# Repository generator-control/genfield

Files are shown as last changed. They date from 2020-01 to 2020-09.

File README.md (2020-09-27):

#genfield
This repo started as a clone of the winch battery-to-invertor contactor control repo. See GliderWinchItems/contactor.

The hardware uses the f103Ard pcb (see GliderWinchCommons/embed/svn_sensor/hw/trunk/eagle/f103Ard) to control the generator field and throttle.

The processor is Blue Pill STM32F103 sub-board that mounts on the pcb.
The key configuration items of the board--
- Non-isolated CAN driver 
- Two Hall-effect current sensors for battery and motor currect
- Two isolated FET drivers for contactors using off-board sub-board
- Isolated high voltage measurement via isolated uart RX
- One small fet to pull invertor /enable line

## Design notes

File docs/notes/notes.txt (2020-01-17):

notes.txt
09/21/2019

1.  The "rig" was put together for test & debugging, so some repackaging
might be in order.

2. Blue Pill high voltage module glued to platform

Therefore, platform needs a spacer to sit flat.

3. Tamura 100a included

I had one with no immediate need. Calibration is based on this unit.

4. Screws

These are wood screws. They tend to crack the the top few layers of 
the post when they are screwed in. One hears a slight crack when 
they are first screwed in. At the time I had not found a source of 
self-tapping plastic screws.

5. Cabling ready to test

The interconnections are in place. These could be replaced by 
hard-wiring for a final package. Vias beside each RJ jack allow
easy soldering.

6. Aux contact feature not tested.

If something in the sw does not work with the Aux contact
feature the failure is to not connect. 

The hw has pull-up resistors so open circuit should appear as a
one bit in the sw. The hw should pull the line to gnd for closed
contact. The sw has a provision for reversing the sense for the
sw.

7. DMOC enable

The only test on this is that it pulls the line down for enable.
This is done after the program is in the CONNECTED state, which
has included a final contactor closure delay.

8. Flashing programs

I'm out of DiscoveryF4 boards, otherwise I would have included
one. The .doc file has a description of the connections for
using a DiscoveryF4 board.

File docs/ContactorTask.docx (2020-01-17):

A. Overview

The objective of the contactor “project” (project in the STM32CubeMX terminology) is to control the contactors that connect the battery string to the motor inverter (DMOC). A key part of this is pre-charging the DMOC capacitor so that when the contactor is closed the current surge is with the limits of the contactor contact rating.

Two modes are accommodated. A two contactor mode is based on two contactors. Contactor #1 connects the battery string to the DMOC plus. Contactor #2 connects the DMOC minus to the battery string minus. The pre-charge resistor is across contactor #2 contacts and when it is closed it shorts the pre-charge resistor.

The one contactor mode has one contactor (designated #1) and a small pre-charge relay (designated #2). The pre-charge relay connects the battery string to the DMOC plus via a pre-charge resistor. When the DMOC capacitor is charged sufficiently, the contactor is closed. The DMOC minus connects directly to the battery string minus.

Also involved is to detect special conditions and failures. E.g. if the battery string voltage is too low a command to connect will put the ContactorTask state in a fault condition and not respond to connect commands.

This project organization is based on using STM32CubeMX and FreeRTOS, and be event driven.

B. Hardware

The program is based on the f103Ard pcb in the following directory which is a motherboard for the Blue Pill module-- ~/GliderWinchCommons/embed/svn_sensor/hw/trunk/eagle/f103Ard

Three additional boards are connected to the f103Ard board: two fethe sub-boards which hold the isolated FET driver and FET for driving the contactor coil, and one custom module constructed on a perf-board with a Blue Pill module for isolated measurement of voltages of battery string and DMOC input.

1. f103ARd—Blue Pill Motherboard

The eagle files for this board can be found in--

~/GliderWinchCommons/embed/svn_sensor/hw/trunk/eagle/f103Ard

A key reference to the board usage is in the following--

~/GliderWinchItems/contactor/README.pins

Some modifications have been made to the board.

The connector arrangement, top view, with CAN RJ 45 jacks at the lower left hand--

a) Serial port: above the dc-dc switcher module, is a six pin header for FTDI type uart<->usb, used for debugging and console monitoring.

1) Gnd – rightmost pin

2) nc

3) nc

4) tx (on ftdi module)

5) rx (on ftdi module)

6) nc

b) Programming port: 4 pin header at bottom of Blue Pill module

1) gnd – rightmost pin|connects to Discovery hdr pin 3

2) – connects to Discovery hdr pin 2

3) – connects to Discovery pin 4

4) +3.3v (not used if motherboard powered from CAN) | connects to Discovery 3.3v on 50 pin hdr, if 3.3v power needed.

Note:

- The pin order of pins 2 & 3 reverses between the Blue Pill and Discovery.

- Discovery pins 1,5, 6 are not connected.

- The two SWD jumpers are removed on the STLINK hdr

c) DMOC enable—three pin, keyed, approximately center

FET pull-down for DMOC hardware enable.

1) gnd

2) FET drain

3) available for diode in case pwm an inductive load used. The diode is not installed.

d) RJ11 jacks for external units

Top left: isolated uart input from Blue Pill isolated high voltage sensor module

Top right: Hall-effect current sensor for battery string current

Bottom left: drive for isolated FET driver for contactor #1

Bottom right: drive for isolated FET driver for contactor #2 (or relay)

2. fethe—isolated FET driver sub-boards

The eagle files for this board can be found in--

~/GliderWinchCommons/embed/svn_sensor/hw/trunk/eagle/fethe

These boards hold the isolated FET driver, and power FET for driving the contactor coils.

R11 jack connects to the BP Motherboard

green led is on when Motherboard drive is high

green led is on FET drive plus is present

Connections

Three large holes, top, left--

gnd – contactor coil power ground (e.g. 12v minus)

+ - connect to 12v plus IF diode for pwm’ing coil is used

nearest FET – FET drain connect to contactor coil.

Note: instead of RJ11 cabling, direct wiring can be done using the viasadjacent to the RJ 11 jacks. Pass one wire through the via for strain relief and solder to the adjacent via, etc.

The right half of the fethe sub-boards are for various types of Hall-effect sensors and not use for this project.

3. Blue Pill isolated high voltage module

This board uses a Blue Pill module to measure four voltages with a common ground, with the ground isolated. A dc-dc module supplies 5v from the Motherboard. A photocoupler isolates the uart tx to the Motherboard.

The eagle files for this module can be found in--

~/GliderWinchItems/bpsensor/hw/eagle/bpsensor

The program layout is a clone of the contactor program with unused code removed.

The high voltage inputs go into a 2.2meg | 15K resistor divider.

Note: when programming the Blue Pill on this module the Discovery board and usb to the PC are NOT ISOLATED!

4. simulation module

The eagle files for this module can be found in--

~/GliderWinchItems/contactor/hw/eagle/simulator

This module is used for testing/debugging and simulates the two contactor modes. It does not simulate the auxiliary contact features and these have not bee tested in the program.

Connections to the module--

Note—the connectors are NOT keyed. Be careful!

top left: contactor #1

bottom left: contactor #2

gnd) connects to gnd (near FET on fethe subboard)

signal) connects to FET drain on fethe subboard

12v) connects to

a) fet driver supply pin

b) plus (diode) IF pwm of coil used

top middle: 12v supply

This supplies both the fet drive power and simulates a 12v battery string.

Bottom center—high voltage sensor connections

gnd – battery minus

1 – (hv1) battery string voltage

2 – (hv2) DMOC plus

3 – (hv3) DMOC minus

HV3 measures the voltage across the pre-charge resistor for the two contactor mode. (HV1-HV2) measures the voltage across the pre-charge resistor for one contactor (w pre-charge relay) mode.

Right most—discharge hdr

When the connect sequence ends the capacitor is charged and needs to be discharged for the next test cycle. A pushbutton plugged into the header allows for manually discharging the capacitor.

LEDs--

Dull green – 12v is present

Clear red (top) contactor #1 coil energized

Clear red (bottom) contactor #2 energized

Pre-charge capacitor simulation--

Resistor = 1K + 2.2K; Capacitor = 1000u

The 2.2K resistor was added to slow the charging to make it easier to observe what the program was doing.

Small resistors are in series with the 12v supply input and discharge hdr to limit smoke and dismay when bumbling about.

C. Program layout

STM32CubeMX generates ‘main’ plus the HAL and FreeRTOS routines. Added to the generated directories are the directories Ourwares and Ourtasks. Outwares holds our routines generally used across the winch applications. Ourtasks holds routines more specific to the project. The distinction is not rigid.

Makefile is generated by STM32CubeMX and is updated when ‘MX regenerates the project, if additional ‘MX files are added. To compile files from Ourwares and Ourtasks the lines are added to Makefile, but fortunately ‘MX does not overwrite the added lines. The list of files to be compiled in Makefile is obvious.

If floating point output in printf is used the Makefile LDFLAGS is modified to -u _printf_float instead of the -nano.

When main.c is generated by ‘MX the only task created is defaultTask. The initialization code is augmented with calls to files in Ourtasks and Ourwares for creation of tasks, buffers, etc. When there is a failure morse_trap is called and the green LED on the Blue Pill flashes a numeric code. A search of the files will turn up the location of the code.

Upon successfully completing the initialization phase of main, main calls the FreeRTOS scheduler and at that point it the various tasks are running. The defaultTask toggles the led every second as an indication that at least the defaultTask is running OK. If the it doesn’t toggle a likely problem is that there is a crash. Running openocd and telenet localhost 4444 and looking at the pc is the starting point. There are some asserts in FreeRTOS which can hang the program, e.g. trying to set a software timer with a timeout count of zero.

Besides initialization in main.c there is initialization in the tasks, e.g. obtaining a buffer for serial output. These can fail and have morse_traps for identification.

The main driver of the logic of the project is ContactorTask. The other tasks are more support for this task. The tasks running (the following in the order they are created in main initialization)--

1. defaultTask

One per second output of monitoring msgs, e.g. task stack usage, ADC readings, etc. Uses yprintf.

2. SerialTaskSend

Sending uart msgs from any task.

3. SerialTaskReceive

Receiving uart lines.

4. CanTxTask

Sending CAN msgs.

5. ContactorTask

Logic and operation of contactors.

6. MailboxTask

Sets up mailboxes for received CAN msgs and notifies task associated with the mailbox. can_iface interfaces our handling of CAN tx and rx msgs with the STM32CubeMX HAL CAN routines. The incoming CAN msg interrupt results in notification of a task, whose task-handle was initialized in the control block for that particular CAN module. (In the Blue Pill there is only one CAN module, but most F4 series can have two, and there are three in the F413 and F767.)

7. ADCTask

Sums ADC readings for DMA ½ and applies initial calibration.

8. Software timer 1

Periodic timer for keepalive/command msgs. Incoming command msgs reset the keepalive and result in a a status CAN msg response. When it times out the periodic callbacks send a status msg as a heartbeat in the absence of keepalive/command msgs.

9. Software timer 2

One-shot timer for waiting for expected contact closure, opening, etc.

10. Software timer 3

Timer to detect failure to receive the isolated high voltage readings.

Note: this task might be eliminated by using timer 1 to check if high voltage readings are not arriving.

D. ContactorTask specifics

This task is the central command for the contactor operation.

Following the initialization the endless loop--

1. Wait for notification

This is similar to ‘select’ in unix. It waits for one or more notifications to arrive. When a notification arrives a bit is set in a ‘noteval’ that identifies the source of the notification. The following notifications are in the program--

/* Task notification bit assignments. */

#define CNCTBIT00 (1 << 0) // ADCTask has new readings

#define CNCTBIT01 (1 << 1) // HV sensors usart RX line ready

#define CNCTBIT02 (1 << 2) // spare

#define CNCTBIT03 (1 << 3) // TIMER 3: uart RX keep-alive

#define CNCTBIT04 (1 << 4) // TIMER 1: Command Keep Alive

#define CNCTBIT05 (1 << 5) // TIMER 2: Multiple use delays

/* MailboxTask notification bits for CAN msg mailboxes */

#define CNCTBIT06 (1 << 6) // CANID_CMD: incoming command: cid_cmd_i

#define CNCTBIT07 (1 << 7) // CANID-keepalive connect command: cid_keepalive_i

#define CNCTBIT08 (1 << 8) // CANID-GPS time sync msg (poll msg): cid_gps_sync

2. Event handling

The notification is some sort of event. Each notification bit is checked and the associated notification is handled. E.g. a uart line received from the high voltage sensor requires extracting the three readings from the line and applying a calibration. The above notification list is also the event handling list.

Most notifications do not generate any actions. One exception is the keepalive/command timer timeout. When that occurs a CAN msg response with the status is always returned.

3. States

Following the handling of events, the current state is checked, i.e. any event results in a pass through the current state logic. A switch statement on the current state code calls a routine that handles that state. (Since these states are rather simple, the routines for all the states are combined into one .c file. For complicated situation each state might warrant a separate file.)

4. Output updates

Following the handling of the states any udpates to outputs are executed. The execution of states sets bits in an output status word and the outputs are updated (e.g. de-energizing contactor coils).

The conclusion of the updates ends the wait loop. The word with the notification bits handled during the loop feed back into the next wait-for-notification, to reset the bits in the FreeRTOS internal notification word. This sequence takes care of the case of notifications arriving during the execution of the loop.

E. States – brief

The list of states with very terse and incomplete description--

1. DISCONNECTED

This the initial state and final state with the contactors open. The DMOC enable FET is off. If the battery is voltage is too low the state will move to FAULTING, and onward to FAULTED.

2. CONNECTING

This and its substates take care of the sequence of energizing the contactors, checking the charging voltage, and either ending up going to FAULTING and onward to FAULTED.

3. CONNECTED

Contactors closed. DMOC enable FET is on. Only commands to disconnect or reset will exit this state to DISCONNECTING and onward to DISCONNECTED.

4. FAULTING,

Deals with de-energizing the contactors and the delay for opening.

5. FAULTED

Stuck in this state until a RESET command is received. A code specifying the reason for the fault shows up in the status msgs.

6. RESETTING

Almost the same as DISCONNECTING except for the resetting of the fault code.

7. DISCONNECTING

Similar to FAULTING except the end-point is DISCONNECTED rather than FAULTED.

8. OTOSETTLING

One time only state for readings to settle.

F. States – a little more description

We start with contactors open, etc. and the state being "disconnected."

Abbreviation:

KA - KeepAlive/command msg

Aux = Auxiliary contact

DISCONNECTED state

This state is changed when:

1) Battery string voltage is less than require to start a launch--

Set code number for battery string low.

New state: FAULTING

2) If Aux contacts are present on contactor #1, AND Aux 1 does not show OFF--

Set timer2 for longest of the two contactors opening delay

New state: FAULTING with code number for this fault.

3) If Aux contacts are present on contactor #2, AND Aux 2 does not show OFF. (Obviously, when there is one contactor and a pre-charge relay, there would be no Aux 2 contacts)--

Set timer 2 for contactor #2 opening delay

New state: FAULTING with code number for this fault.

4) CAN command (keep-alive) msg "connect" is received.

Set software timer2 for contactor #1 closure delay--

(approx 25 ms and if it has aux contacts this parameter might have to include

some delay if the aux contact close a bit behind the main contacts)

Set connecting substate to C1

New state: CONNECTING

CONNECTING state

substate C1 closing contactor #1

This state changes when:

1) Timer2 times out

Contactor #1 should now be closed, contactor #2 still open.

If aux1 present, and is not ON, then

Set code for aux1 not closing

New state: FAULTING

else

If two contactor config, and hv2 not approx equal hv1, then

Set code for contactor #1 didn’t close

New state: FAULTING

Set timer2 to minimum pre-charge duration (approx 3 secs)

New state: substate C2

substate C2 charging DMOC capacitor

This state changes when:

1) Timer2 times out.

Set timer for limit to extended pre-charge duration (4 secs?)

New state: substate C3

substate C3 charge DMOC cap until cutoff voltage

This changes state when:

1) If two contactors

hv3 is less than cutoff voltage (e.g. 10v)

else

(hv1-hv2) less than cutoff voltage

Set timer2 for contactor #2 closing delay

New state: substate C4

substate C4 contactor #2 closing

This changes state when:

1) If aux2 present and aux2 not closed

Set fault code: contactor #2 aux not closing

New state: FAULTING

2) Timer 2 times out.

If one contactor config,

de-energize contactor #2 (pre-charge relay)

New state: CONNECTED

CONNECTED state

This changes state when:

1) KA disconnect or reset commands received

Set timer2 to longest of contactors open delays.

New state: DISCONNECTING

DISCONNECTING state

Changes state when:

1) timer2 times out.

New state: DISCONNECTED

FAULTING state

Changes state when:

1) timer2 times out

New state: FAULTED

FAULTED state

The fault code list--

enum CONTACTOR_FAULTCODE

{

NOFAULT,

BATTERYLOW,

CONTACTOR1_OFF_AUX1_ON,

CONTACTOR2_OFF_AUX2_ON,

CONTACTOR1_ON_AUX1_OFF,

CONTACTOR2_ON_AUX2_OFF,

CONTACTOR1_DOES_NOT_APPEAR_CLOSED,

PRECHGVOLT_NOTREACHED,

CONTACTOR1_CLOSED_VOLTSTOOBIG,

CONTACTOR2_CLOSED_VOLTSTOOBIG,

KEEP_ALIVE_TIMER_TIMEOUT,

};

Changes state when:

1) KA command reset received

Clear fault code

New state: DISCONNECTED

G. Parameter list

Parameters are organized along the lines used for the bare metal and Derby database scheme. In the data base scheme parameters for a function are designated in PARAM_LIST_INSERT.sql and values for each instance of the function specified in PARAM_VAL_INSERT.sql. These files are found in

GliderWinchCommons/embed/svn_common/trunk/db

A java program outputs a file with these values as a struct in a .c file, which is compiled and loads into high flash for semi-permanent storage of the parameters for the particular instance of the function. When the program boots it copies the value in high flash into a sram working struct.

For contactor, the database/high-flash part is skipped and a routine with the parameter values hard-coded copies the parameters into the sram working struct. If the database/high-flash part is implemented (making possible online update of parameters) the only change for contactor would be to change the routine that hard-code initializes the working struct to one that copies the values from high-flash to the working struct.

For contactor there are two parameter lists. One is for the contactor function and the other is for the ADC. In the general sense the ADCs (as many as three modules) could serve multiple functions, however making a general multi-function interface is messy, e.g. one could use three of the ADCs, but only ADC1 accesses the internal voltage reference and temperature sensor, etc. Therefore, the parameters for the ADC were grouped separately from the contactor parameters.

The naming convention for the parameters is struct <NAME>LC (LC = Local Copy) giving rise to a .c and .h file. In this case--

adc_idx_v_struct.c [hard code set values]

adc_idx_v_struct.h [parameter struct definition]

contactor_idx_v_struct.c [hard code set values]

contactor_idx_v_struct.h [parameter struct definition]

A function instance requires more than just the parameters, so a struct is defined that contains the parameter struct plus the other other working variables. The naming convention for these structs is <NAME>FUNCTION.

adcparams.c

adcparams.h

ContactorTask.c

ContactorTask.h

In ContactorTask.h above the contactor function struc begins as--

struct CONTACTORFUNCTION

{

// Parameter loaded either by high-flash copy, or hard-coded subroutine

struct CONTACTORLC lc; // Parameters for contactors

struct ADCFUNCTION* padc; // Pointer to ADC working struct

The first entry, struct CONTACTORLC lc; // Parameters for contactors is the parameter struct for contactor. The second entry is pointer (mostly for convenience) to the adc function working struct. With this layout a single pointer to the contactor function struct accesses “everything” that is either a variable or parameter. The only parameters that might be in the executed code would be some universal scaling constants.

When the program starts the initialization calls the .c files above which in the case of the parameter list loads the parameters values into the working struct. A subsequent call to the .c files for the function struct initializes the working parameters, such as converting specified parameters such as milliseconds into timer ticks, and converting floating point (e.g. voltages) into scaled integers, range checks on parameters, pre-computing ratios for ADC calibrations, etc.

H. ADC

The ADC scans six channels, storing the 12b readings in a DMA circular buffer. The DMA interrupts at the ½ and end points of storing in the buffer, and the buffer length holds sixteen scans (six reading per scan) in each half. Upon a DMA interrupt the sixteen readings are summed for each channel. Since the maximum reading possible is 4095, the maximum sum is 65520 which fits in a uint16_t. The DMA interrupt notifies the ADCTask which carries out the summation and subsequent calibration of the readings.

The ADC calibration is based on using the internal voltage reference (Vref) rather than Vdd as the Vref is more stable. In the DiscoveryF4 Vdd can vary between about 2.85v and 3.3v depending whether the power source is the USB, as there is a diode drop involved. For the Blue Pill there is a 3.3v regulator and no diode involved, but the internal reference is more stable than the regulator.

The ADC routines in contactor deal with two types of measurements. One is absolute and the other ratiometric. The absolute measurement is based on the ratio of the ADC readings of the input to be measured and the Vref, and knowing the value of Vref. The result is independent of Vdd. The 5v and 12v supply voltages are examples. (For the high voltage sensor, the three high voltages would be absolute types of measurements.)

The ratiometric type of input is based on the ratio of the input to be measured and the ADC reading of the 5v supply. The Hall-effect current sensors use the 5v supply and output a signal from 0 – close to 5v. Their output is divided to limit the max voltage to the ADC to about 2.9v. The 5v supply is divided similarly. Knowing the ratio of the two dividers the result is independent of the 5v supply variations.

To simplify calibration, calibration parameters are specified in floating pt format, e.g. 5.03 volts. For computations the floating pt is scaled and computations done with integers.

A single pole iir filter, using int32_t, and expecting 16b numbers is used to smooth the summed ADC readings. The filter time constant and integer scaling are parameter inputs for each ADC channel.

(NOTE: filtering is provided by currently being skipped and the unfiltered readings used.)

For the contactor states that check for voltages above/below some threshold value, the threshold that is specified in floating pt is converted to a scaled uint32_t.

The internal temperature sensor is currently measured, but the formula to convert it to temperature is currently not coded. The code in F1 series is somewhat different than the F4 series that has calibration constants in the system memory. The temperature is chip temperature and as such not of much value for measuring ambient temperature, however it has use for compensating the internal reference voltage.

I. CAN msgs

ContactorTask.h has a summary of the CAN msg in the comments at the beginning of the file.

1. Function commands

The function command is a diagnostic/maintenance type of command. The early thinking was that one CAN id would be used to take of care of communication involving such things a online parameter update and retrieving variables that are not part of the operational aspect of the function. The hex CAN id is added to the database table CANID_INSERT.sql, and used in the initialization of the contactor parameter struct (see contactor_idx_v_struct.c).

For contactor retrieving raw ADC readings to be used in conjunction with an applied calibration voltage or current would be the main use of the function command.

cid_cmd_i (incoming) specifies a request in the first payload byte

cid_cmd_r (response) returns the requested readings

The first payload request byte code is specified in contactor_cmd_msg.c --

enum CONTACTOR_CMD_CODES

{

ADCRAW5V, // PA0 IN0 - 5V sensor supply

ADCRAWCUR1, // PA5 IN5 - Current sensor: total battery current

ADCRAWCUR2, // PA6 IN6 - Current sensor: motor

ADCRAW12V, // PA7 IN7 - +12 Raw power to board

ADCINTERNALTEMP, // IN17 - Internal temperature sensor

ADCINTERNALVREF, // IN18 - Internal voltage reference

UARTWHV1, // Battery voltage

UARTWHV2, // DMOC +

UARTWHV3, // DMOC -

CAL5V, // 5V supply

CAL12V, // CAN raw 12v supply

};

ADC requests send back a seven byte payload--

byte[0] : return of request code

byte[1]-[2]: 16b ADC sum reading

byte[2]-[6]: Float of calibrated reading

The high-voltage readings (essentially the same as ADC)--

byte[0] : return of request code

byte[1]-[2]: 16b sensor ADC reading sent via uart

byte[2]-[6]: Float of calibrated reading

CAL5V and CAL12V are the same as the ADC requests.

2. Polling

The contactor sends can send two CAN msgs in response to the CAN poll msg cid_gps_sync used for polling the POD. See contactor_idx_v_struct.c--

// CANID_HEX CANID_NAME CAN_MSG_FMT DESCRIPTION

p->cid_msg1 = 0x50400000; // CANID_MSG_CNTCTR1V : FF_FF : Contactor1: poll response: High voltage1:Current sensor1

p->cid_msg2 = 0x50600000; // CANID_MSG_CNTCTR1A : FF_FF : Contactor1: poll response: battery gnd to: DMOC+, DMOC-

One is for battery string voltage 1 and battery current 1 and the other for voltages between battery ground and DMOC+, DMOC-. These are sent in an eight byte payload as a pair of floats with units, volts & amps.

3. Heartbeat

Heartbeat messages have the same payload format as the Polled msgs, but lower priority CAN ids.

p->cid_hb1 = 0xFF800000; // CANID_HB_CNTCTR1V : FF_FF : Contactor1: Heartbeat: High voltage1:Current sensor1

p->cid_hb2 = 0xFF000000; // CANID_HB_CNTCTR1A : FF_FF : Contactor1: Heartbeat: High voltage2:Current sensor2

4. Keepalive/command

The keepalive msg carries the command to connect/disconnect/reset and also serves to let the contactor know that there is communication with the controller.

cid_keepalive_i (incoming) command

cid_keepalive_r (response) status

The response sends the current status. It is sent in response to each incoming keepalive msg and also whenever the state changes. If the keepalive msgs cease the keepalive timer timeout causes a status msg to be sent, making it like a heartbeat msg with the status.

J. cangateCON—cangate version for testing contactor

cangateCON is located in--

~/GliderWinchCommons/embed/svn_discoveryf4/PC/sensor/cangateCON/trunk

This version of cangate has some commands specific for testing the contactor. To compile cangateCON

cd to the above directory and type ./mm<enter>

To execute cangateCON (after setting up a gateway and hub-server)--

cd ~/GliderWinchCommons/embed/svn_discoveryf4/PC/sensor/cangateCON/trunk

./cangateCON 127.0.0.1 32123

More on setting up the whole test rig later.

command k

k - CONTACTOR: keep-alive

ka - Begin sending keep-alive msgs

kx - Stop keep-alive msgs

k0 - disconnect

k1 - connect

k2 - reset

This command handles the keepalive CAN msgs to/from the contactor.

Entering ‘k’ starts the command and keepalive msgs from contactor are decoded and displayed. The msgs from contactor may be either responses to keepalive msgs sent by cangateCON, or heartbeat msgs which are sent when the contactor keepalive timer has timed out, i.e. contactor was not receiveing keepalive msgs.

The keepalive msgs from contactor carry the status which is displayed, both with the numeric fields and ascii text for the codes that show the status of the contactor program progress.

After starting command ‘k’,

ka – starts sending keepalive msgs. The rate of status msgs from contactor will be faster than the heartbeat msgs.

kx – stops sending keepalive msgs.

k0 – disconnect command

returns contactor to disconnected state

k1 – connect command

starts the sequence for connecting

k2 – reset fault

When contactor goes into a fault state it remains until ‘k2’ sets the reset bit in the command msg.

command b

b - CONTACTOR: display polled msgs

Entering ‘b’ alone displays options

bp<enter>

CONTACTOR msg gps msg POLLED

default CAN IDs 50400000 50600000

bp aaaaaaaa bbbbbbbb<enter>

a = CAN ID msg1, b = CAN ID msg2

bh<enter>

CONTACTOR msg gps msg HEARTBEAT

default CAN IDs FF800000 FF000000

bh aaaaaaaa bbbbbbbb<enter>

a = CAN ID msg1, b = CAN ID msg2

The default CAN id for two CAN msgs from contactor are displayed. These can be overridden by entering ‘bp’ followed by the two CAN addresses. Note, one could display CAN payloads from any CAN msg(s) where the payload is two floats, i.e. the display is rather generic.

Entering ‘bp’ without additional data uses the default CAN addresses and displays polled msgs contactor sends in response to the gps/time sync msgs (64/sec). The polled response is two msgs that carry the three high voltage readings plus the current, all as floats in volts, or amps.

For example entering bp displayed, HV1, current, HV2, HV3 at 64 lines/sec--

Display two payload float pairs using CAN IDs: 50400000 50600000

12.468 0.000 0.027 0.027

12.458 0.000 0.027 0.027

…

Note that each line is payload from two CAN msgs and expects both msgs.

bh – same display as bp, but for heartbeats.

command s

s - CONTACTOR: command request to retrieve all readings

Send the maintenance commands and display the responses. CangateCON sends CAN msg to contactor. The first payload byte contains the code number for data. The response repeats the request code and adds the data.

ID: CAN node sends to us: E3600000 We send to CAN node: E360000C

TX: e360000c 1 0 : RX E3600000 7 00 FB F9 00 00 00 00 0: 63995 0.00 ADCRAW5V, PA0 IN0 - 5V sensor supply

TX: e360000c 1 1 : RX E3600000 7 01 BB B1 00 00 00 00 1: 45499 0.0 ADCRAWCUR1, PA2 IN2 - Current sensor: total battery current

TX: e360000c 1 2 : RX E3600000 7 02 C3 90 00 00 00 00 2: 37059 0.0 ADCRAWCUR2, PA4 IN4 - Current sensor: motor

TX: e360000c 1 3 : RX E3600000 7 03 75 3F 00 00 00 00 3: 16245 0.0 ADCRAW12V, PA7 IN7 - +12 Raw power to board

TX: e360000c 1 4 : RX E3600000 7 04 27 69 B6 23 0D 42 4: 26919 35.3 ADCINTERNALTEMP, IN17 - Internal temperature sensor

TX: e360000c 1 5 : RX E3600000 7 05 32 5D 00 00 00 00 5: 23858 0.000 ADCINTERNALVREF, IN18 - Internal voltage reference

TX: e360000c 1 6 : RX E3600000 7 06 38 05 DE 55 47 41 6: 1336 12.46 UARTWHV1, Battery voltage

TX: e360000c 1 7 : RX E3600000 7 07 03 00 ED 77 DE 3C 7: 3 0.03 UARTWHV2, DMOC +

TX: e360000c 1 8 : RX E3600000 7 08 03 00 69 C7 DE 3C 8: 3 0.03 UARTWHV3, DMOC -

TX: e360000c 1 9 : RX E3600000 7 09 00 00 00 00 00 00 9: 0 0.000 CAL5V, 5V supply

TX: e360000c 1 10 : RX E3600000 7 0A 00 00 00 00 00 0010: 0 0.000 CAL12V, CAN raw 12v supply

TX: e360000c 1 11 : RX E3600000 7 0B

Two instances of cangateCON, one with command k running, and one with command b running allow monitoring the pre-charging and status.

K. Running the test setup

The following three units are needed to run the test setup. Other units can also be on the CAN bus.

1. CAN bus

a) gps/logger generating time sync msgs

To observe the polled contactor msgs it needs time sync CAN msgs from the gps/logger.

b) gateway

c) contactor BP Motherboard

2. USB

A usb hub is needed for the following--

a) gateway FTDI module (for hub-server/socat to CAN bus)

b) contactor BP Motherboard: console monitoring

c) Discovery F4 STLINK (for reprogramming contactor)

3. contactor wiring

a) Wired to simulator, BP high voltage sensor modules and fethe subboards as described earlier.

b) Set jumpers for mode--

all to left = two contactor mode

all to right = contactor mode

c) Set use/ignore high voltage readings jump

not jumpered = use high voltage readings

jumper present = ignore high voltage reading logice

d) 12v to simulator module (which also powers the fethe boards).

e) Check that the following LEDs are “working”--

Both Blue Pill modules on the Montherboard and high voltage sensor should have a steady red led (showing it is powered) and one per second flashing green led (showing the program is running OK).

Each fethe subboard should have a steady bright green LED on (12v fet driver power).

Simulator module should have the dull green LED on (12v power).

4. Open window and Start hub-server and cangateCON

a) Determine port number of FTDI from gateway.

List serial ports devices--

ls /dev/ttyUSB*

Pull USB plug from the hub for gateway.

Up arrow and run above command again.

Note which device missing, e.g. dev/ttyUSB1

b) Start hub-server

hub-socat_b 32123 /dev/ttyUSB1 2000000

32123 = port number to be used

/dev/ttyUSB1 = gateway port as determined above

2000000 = baud rate for gateway<->socat

c) Check that hub-server is working

nc localhost 32123

CAN msgs should be seen ripping by.

d) Start an instance of cangateCON

Go to cangateCON directory--

cd ~/GliderWinchCommons/embed/svn_f~/GliderWinchCommons/embed/svn_discoveryf4/PC/sensor/cangateCON/trunk

./cangateCON 127.0.0.1 32123

The menu should come up--

### CANGATECON ### 08/03/2019

BAUDRATE is FIXED AT: 2000000 baud

argc 3

0 ./cangateCON

1 127.0.0.1

2 32123

Socket opened OK. IP: 127.0.0.1 PORT: 32123

CANID sql file opened!: ../../../../../svn_common/trunk/db/CANID_INSERT.sql

Control C to break & exit

a - ascii monitor of a CAN unit

d - list raw msgs

f - display fix: (e.g. f<enter>, or f E2600000<enter>

h - Photodetector level histogram from sensor

l - list unix time/date in heartbeat time msgs (l e1000000)

n - list msg id's and msg ct during 1 sec (coarse computer timing)

u - list msg id's and msg ct between CAN 1 sec time mgs (e.g. u 00600000)

m - list msgs for id entered 'm xxxxxxxx (CAN ID as 8 hex digits)'

q - Identify received msgs from CANID.sql file

r - send high priority RESET

s - CONTACTOR: command request to retrieve all readings

k - CONTACTOR: keep-alive

ka - Begin sending keep-alive msgs

kx - Stop keep-alive msgs

k0 - disconnect

k1 - connect

k2 - reset

b - CONTACTOR: display polled msgs

c - request & display launch parameters

w - list msgs float (wf) or integer (wi) payload with payload byte offset (wi1 E1800000)

x - cancel command

Control C to quit program

Enter command u--

CAN msg counts should appear if gps/logger is putting out time sync msgs. If not,

Try command n.

Enter command k for contactor. Something similar to the following should begin--

Using DEFAULT CAN IDs: Send E3800000 Rcv E3C00000

to use different CAN IDs, enter exactly in the following format

k aaaaaaaa bbbbbbbb<enter>

where: a = ID PC sends, b = ID PC receives

KA response (status): E3C00000 3 80 00 03 : 0 3 DISCONNECTED : NO_FAULT

KA response (status): E3C00000 3 80 00 03 : 0 3 DISCONNECTED : NO_FAULT

KA response (status): E3C00000 3 80 00 03 : 0 3 DISCONNECTED : NO_FAULT

…

e) Open a window and start minicom for console monitoring

Do a ‘ls /dev/ttyUSB*’, then pull the usb plug to the hub for the console FTDI module and repeat the command to see which port the console is on. Start minicom.

The console output depends on the sections of code enabled in the ‘main.c’ task--

void StartDefaultTask(void const * argument)

For example, the following updates at about once per second--

# 7 Unused Task stack space--

#Stack: defaultTask--- 109

#Stack: SerialTaskSend 92

#Stack: CanTxTask----- 84

#Stack: MailboxTask--- 64

#Stack: ADCTask------- 85

#Stack: ContactorTask- 76

#Stack: SerialReceiveTask 70

#GetFreeHeapSize: total: 7200 free 600 8.3% used: 6600

63995 45457 37097 16271 27127 23872 : 27129 372.9

UART ctr: 531

uart_hv 1337 1376 3

dscale0.0093252 0.0090523 0.0090649

hvcal 1222 1186 1188

hvc 1632592 1631936 3564

hv 1336 1376 3 <= from BP voltage sensor

dhvc 12.47 12.46 0.03 <= after calibration

ibattlow: 965 fbattlow: 9.00 hv[0]: 1336 battnow: 12.46

iprechgendv: 66 hv[IDXHV3].hvc: 3

HV by-pass pin: 1

THRES: 1752 78625 1631370 1633122 0

5. Open terminal window to observe contactor voltages/current

Start cangateCON. ‘cd’ to directory, as above, and start with same command line.

Enter command ‘bp’

The readings should be running past--

HV1 | current : HV2 | HV3

Press pushbutton to discharge capacitor. HV2 will likely drop somewhat. The latest offset was 0.027 volts.

6. Operate contactor

In the window with the ‘k’ command, running ‘ka’, it should be showing DISCONNECTED : NO_FAULT

If it is showing a fault, enter ‘k2’ to reset the fault state.

Enter ‘k1’ to start the connection.

Two contactor mode--

HV2 should jump to the batttery string voltage (i.e. the 12v supply).

HV3 should jump from near zero to nearly equal to the HV1, the battery string (12v supply) reading and begin dropping as the capacitor charges.

The status msgs should show “CONNECTING”.

The substate code will step to 1 for the minimum duration pre-charge, regardless of voltage, followed by step 2 which begins checking for the voltage threshold for closing contactor #2. If the threshold is not reached before the time expires it goes to a fault state and with the status message showing the fault.

Varying the timing and voltage parameters and recompiling/flashing can be done to demonstrate the various fault conditions.

L. Program compiling/flashing

1. Connect a DiscoveryF4 or Nucleo board to the Blue Pill programming port.

a) Remove the two jumpers on the STLINK header on the DiscoveryF4 board.

b) Connect the three wires from the SWD (six pin) header on the DiscoveryF4 board to the Blue Pill header as detailed earlier. Note that the wire sequence reverses for one pair.

c) USB cable from usb hub on PC to STLINK connector of DiscoveryF4

2. Open a window and cd to the project code--

cd ~/GliderWinchItems/contactor

Start compilation--

./mm

On my computer success produces--

deh@ASUS:~/GliderWinchItems/contactor$ ./mm

make: Nothing to be done for 'all'.

make: Nothing to be done for 'all'.

---- PATHS for OPENOCD ----

OPENOCD_SCRIPTS: /usr/share/openocd/scripts

OPENOCD_FLAHSER: /usr/share/openocd/scripts/interface/stlink-v2.cfg

OPENOCD_BOARD: /usr/share/openocd/scripts/board/olimex_stm32_h103.cfg

FLASH FILE NAME: /contactor.srec

_FLASHNAME: /usr/bin/make

DIR_SREC: /home/deh/GliderWinchItems/contactor/build

Open On-Chip Debugger 0.9.0 (2018-01-24-01:05)

Licensed under GNU GPL v2

For bug reports, read

http://openocd.org/doc/doxygen/bugs.html

Info : auto-selecting first available session transport "hla_swd". To override use 'transport select <transport>'.

Info : The selected transport took over low-level target control. The results might differ compared to plain JTAG/SWD

adapter speed: 1000 kHz

adapter_nsrst_delay: 100

none separate

Info : Unable to match requested speed 1000 kHz, using 950 kHz

Info : Unable to match requested speed 1000 kHz, using 950 kHz

Info : clock speed 950 kHz

Info : STLINK v2 JTAG v34 API v2 SWIM v0 VID 0x0483 PID 0x3748

Info : using stlink api v2

Info : Target voltage: 2.889882

Info : stm32f1x.cpu: hardware has 6 breakpoints, 4 watchpoints

target state: halted

target halted due to debug-request, current mode: Thread

xPSR: 0x01000000 pc: 0x08009f58 msp: 0x20005000

auto erase enabled

Info : device id = 0x20036410

Info : flash size = 64kbytes

Info : Padding image section 0 with 4 bytes

target state: halted

target halted due to breakpoint, current mode: Thread

xPSR: 0x61000000 pc: 0x2000003a msp: 0x20005000

wrote 62464 bytes from file /home/deh/GliderWinchItems/contactor/build/contactor.srec in 3.646678s (16.728 KiB/s)

shutdown command invoked

deh@ASUS:~/GliderWinchItems/contactor$

During the flashing phase the green LED on the Blue Pill module board will stop. If the program doesn’t crash when it starts up the green LED begins one second on/off flashing again.

Most errors are trapped with the ‘morse.c’ which flashes a two digit code number on the green LED. That code number can be found in the source code to locate where it went wrong. These are generally initialization faults.

If the green LED doesn’t flash there is likely FreeRTOS not happy. The most common problem is there is not enough sram for either system stack or the heap. The allocation can be adjusted

at line 106 in--

~/GliderWinchItems/contactor/Inc/FreeRTOSConfig.h

However, re-running STM32CubeMX will overwrite this if the code is regenerated. Therefore, if a new value is settled upon, go to STM32CubeMX and change it in the FreeRTOS section.

2. Modify parameters

Parameters can be modified to test the functioning of different fault conditions with the simulation module. Modifications will be necessary to adapt it to the real winch.

The parameters of interest are located in the directory--

~/GliderWinchItems/contactor/Ourtasks

The parameters are loaded into a sram struct during initialization. The values are currently loaded by executing the code in--

contactor_idx_v_struct.c

Later, this file could be replaced with loading from a flat file in high-flash that can be updated via CAN, and is independent of re-flashing the program code.

Other files associated with contactor_idx_v_struct.c are--

ContactorTask.h

contactor_func_init.c

hwconfig has bit positions for the configurations. All bits off is the default. These are defined in--

contactor_idx_v_struct.h

fbattlow Defines the voltage below which will cause a low battery fault when in the disconnected state.

The section on timings are in milliseconds, which is converted to parameters to timer ticks during the execution of contactor_func_init.c during initialization.

Of particular interest is--

ddiffb4 – defines the voltage across the contactor (difference before closing) that will end the pre-charging state. If the timer times out during this state, it means the voltage had been expected to be reached, but failed; therefore, it goes to a fault state.

fdiffafter – defines the voltage across final contactor after it has been energized and after a short delay for closure it should be closed, above which results in a fault, which means the contactor may not have closed. There is an issue here with pwm’ing the coil. If the contactor is pwm’ed and the pwm percentage is too low the contactor could drop out. The state logic doesn’t cover this situation.

prechgmin_t – Duration for the minimum pre-charge time. The first phase of pre-charge is always this duration.

prechgmax_t – Following the above minimum duration, this duration times the state that the voltage is checked for terminating the pre-charge. The pre-charge state will be terminated if the voltage threshold is reached, in which case it was successful, or if the timer times out, in which case it failed.

If the jumper for ignoring the high voltage readings is in place, the pre-chargemax time will take place and it will not go to a fault state when the timer times out. Net—the pre-charge duration would be the sum of prechgmin_t plus prechgmax_t.

close1_t, close2_t – These are set long to be able to observer the LED on the simulator module.

PWM parameters are in percentage (0-100). The coil is energized at full ON for close1_t or close2_t duration. At the end of that time duration the FET is pwm’ed at the parameter percentage. The simulator coils drop out at around 40%.

fpwmpct1, fpwmpct2 – percent pwm ON time.

Note: A minor simplification could be made by not specifying if the coils are to be pwm’ed, but instead always pwm the coil (after the initial 100% pull duration), and specify the pwm percentage as 100% (which results in continuous ON) if no pwm is desired.

dcurrentdisconnect – Battery current threshold for disconnecting

Opening the contactors for the DISCONNECTING state is prevented if the battery string current is greater than this parameter. The code assumes the parameter is positive. If the battery string current is negative the logic reverses the sign so that negative battery string currents greater than this parameter also prevents opening the contactors. If this feature is not desired, then set the parameter to an impossibly large value, but so large as to run into scaling problems (since the floating pt parameter is converted to a scale integer which is used for the arithmetic). A value 10% greater than the max of the current sensor would be a good value.

Calibrations

1. High voltage readings

The Blue Pill high voltage sensor sends ADC measurement, and these are then filtered, and adjusted for offset and scale to yield voltage. The defaultTask in contactor ‘main.c’ lists the raw adc readings which can be used to adjust the calibration for the three voltages. The present calibration was done with the 12v supply and can expected to be close for voltages in the 300-400v range.

2. Battery current

The calibration parameters are hard-coded in the file--

adc_idx_v_struct.c

The calibrations for the 12v simulation testing are--

// Battery current: ADC1IDX_CURRENTTOTAL 1 // PA5 IN5 - Current sensor: total battery current

p->cal_cur1.iir.k = 10; // Filter time constant

p->cal_cur1.iir.scale = 2; // Filter integer scaling

p->cal_cur1.zeroadcve = 27183; // connected, no current: HE adc reading

p->cal_cur1.zeroadc5 = 63969; // connected, no current: 5v adc reading

p->cal_cur1.caladcve = 30186; // connected, cal current: adc reading

p->cal_cur1.dcalcur = 9.373; // connected, cal current: current * turns

The two ‘iir’ parameters define the filtering of the ADC readings.

Since the Hall-effect sensor is driven by the 5v supply and is ratiometric, the calibration uses both the sensor readings and the 5v supply readings to compute a ratio.

zeroadcve – This (i.e. the ‘ve’) is the adc reading for the sensor with no current.

zeroadc5 – The 5v adc reading under the same conditions as zeroadcve.

caladcve – The adc reading for the sensor with the calibration current

dcalcur – Calibration current in ‘amp-turns’. For the Tamura sensor multiple turns can be wound to allow a smaller calibration current to simulate a one turn large current, the parameter is the calibration current multiplied by the number of turns. It assumes the 5v supply reading has not drifted from the zeroadc5.

The console monitor, defaultTask, displays the readings--

5v cur1 cur2 12v temp vref

A 63985.9 27199.7 32852.6 16236.4 26867.9 23855.2

Relevant are the 5v and cur1 readings. In the above, the 5v reading is close to 65520, which is the maximum ADC reading summed 16 times, and is a result of the resistor divider. In the above the 27199.7 cur1 reading is the zero-current level.

When the contactor is in the DISCONNECTED state the 5v/cur1 ratio is computed and compared to the previous ratio, which is initially the ratio computed from the calibration values. If this new ratio is greater than +/- ZTOLERANCE, which is defined in adcparams.h, (currently 0.05), then it goes to a fault condition with the fault code for HE_AUTO_ZERO_TOLERANCE_ERR, which is defined in adcparams.h.

The auto-zeroing continues as long as the contactor is in the DISCONNECTED state.

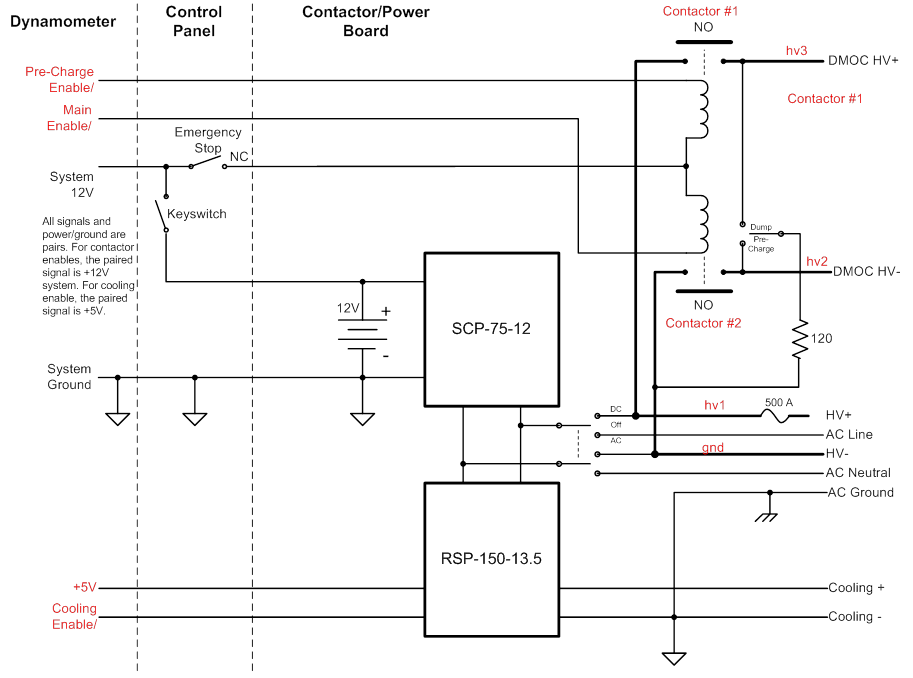
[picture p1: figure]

I have added labels (in red) for items I know. Take a look at this and see what else you would like added, removed, changed… I expect there to be several changes, some I have already thought on, but let me get your thoughts on this before I do more mods.

Contactor project rev 09/15/2019 07/15/2019 25

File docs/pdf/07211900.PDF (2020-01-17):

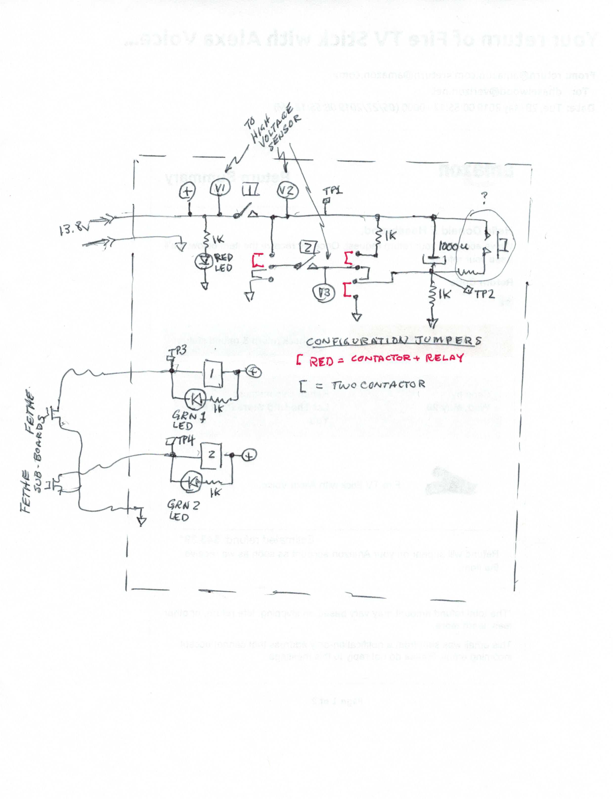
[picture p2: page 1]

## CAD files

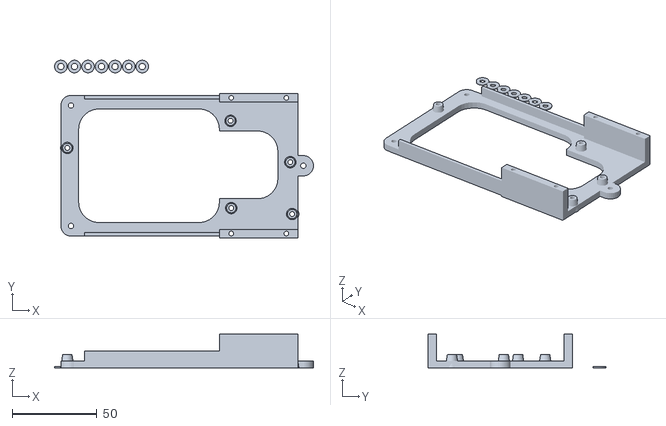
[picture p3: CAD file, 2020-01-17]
hw/openscad/platform2.stl
152.8 x 104.7 x 20.0

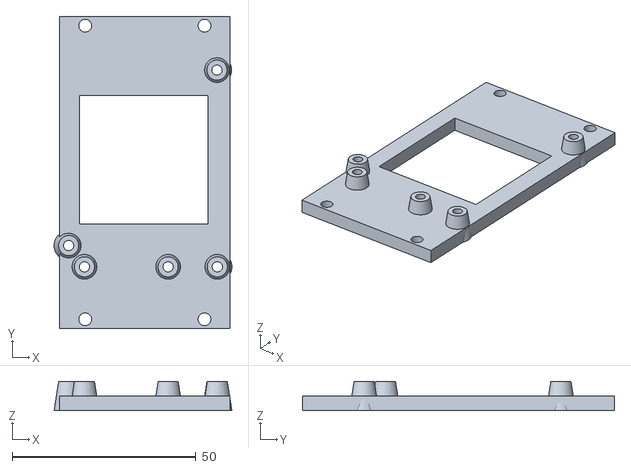
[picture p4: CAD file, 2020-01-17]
hw/openscad/pltop2.stl
48.5 x 85.0 x 8.00

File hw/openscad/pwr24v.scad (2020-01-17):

/* File: pwr24v.scad
 * Platform to hold 24v xfrmr and dc-dc 
 * Author: deh
 * Latest edit: 20200113
 */
 $fn = 30;
 
 thick = 4;

// Base
bx = 110; // Length
by = 85;  // Width
bt = 4;   // Thickness

// Transformer
tfhy = 58;   // Mtg hole spacing
tfhd = 3.5;  // Mtg hole diam

bhox = 3; // Base mtg hole offset from edge: x
bhoy = 3; // Base mtg hole offset from edge: y
module bhole(a)
{
	translate(a)
		cylinder(d =3.6,h=30,center=false);
}

acpx = 4;
acpy = 6;
acpz = 30;

module acpost(a)
{
	translate(a)
	{
		difference()
		{
			union()
			{
			}
			union()
			{
			}
		}
	}
}
dcpx = 4;
dcpy = 6;
dcpz = 45;

module dcpost(a)
{
	translate(a)
	{
		difference()
		{
			union()
			{
			}
			union()
			{
			}
		}
	}
}

module base()
{  
	difference()
	{
		union()
		{
			cube([bx,by,bt],center=false);
		}
		union()
		{
			// Base plate mounting holes
			bhole([   bhox,   bhoy,0]);
			bhole([bx-bhox,by-bhoy,o]);
			bhole([   bhox,by-bhoy,o]);
			bhole([bx-bhox,   bhoy,o]);

			// AC cord pcb posts


			// Rectified & dc-dc swrs post

	}
}

base();

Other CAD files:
hw/openscad/platform2.scad

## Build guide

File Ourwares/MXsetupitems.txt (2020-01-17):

MXsetupitems.txt

Items

1. Serial 

The last argument must match what was setup in 'MX--

/* Add bcb circular buffer to SerialTaskSend for usart1 */
	#define NUMCIRBCB1  16 // Size of circular buffer of BCB for usart6
	ret = xSerialTaskSendAdd(&huart1, NUMCIRBCB1, 1); // dma
	if (ret < 0) morse_trap(1); // Panic LED flashing

2. ADC

In adcparams.h the size must match 'MX--

#define ADC1IDX_ADCSCANSIZE   6 // Number ADC channels read

3.  morse.c

The LED set/reset must match the board, i.e. is the LED energized
by pull-down or pull-up.

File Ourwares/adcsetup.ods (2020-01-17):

 | mxusartusbcan |  | From datasheet formula
 | adc setup |  | Section | 5.3.21
 | 02/02/19 |  | 12-bit ADC | characteristics
 |  | Bus | 84
 |  | Divider | 8
 | K(sampling) | C(pf) | fadc*MHz) | 12bit | Rain |  | Sample tiime
 | 3 | 5 | 10.5 | 9.7040605278 | 5.79 |  | 0.3
 | 15 | 5 | 10.5 | 9.7040605278 | 29.34 |  | 1.4
 | 28 | 5 | 10.5 | 9.7040605278 | 54.86 |  | 2.7
 | 56 | 5 | 10.5 | 9.7040605278 | 109.82 |  | 5.3 |  |  | cts/volt
 | 84 | 5 | 10.5 | 9.7040605278 | 164.78 |  | 8.0 |  |  | 819 | 2.5 | 2047.5 | 2047.5
 | 112 | 5 | 10.5 | 9.7040605278 | 219.74 |  | 10.7 |  |  |  | 2047 | 1842.3
 | 144 | 5 | 10.5 | 9.7040605278 | 282.55 |  | 13.7
dynamometer | 480 | 5 | 10.5 | 9.7040605278 | 942.07 |  | 45.7
'MX
03/15/19 |  |  | ADC | Sample cycles | conv (us) |  |  | Offset | divider | Sensor amps | scale
 | PA1 | IN1 | 1 | 56 | 6.4761904762 |  | spare | ADC cts |  |  | amps
 | PA5 | IN5 | 2 | 56 | 6.4761904762 |  | Total battery current | 2047 | 0.6444444444 | 200 | 0.1086 |  | ACS770ECB-200B-PFF-T
 | PA6 | IN6 | 3 | 56 | 6.4761904762 |  | Current #1 motor | 2047 | 0.6444444444 | 600 | 0.3257 |  | L01Z600S05
 | PA7 | IN7 | 4 | 56 | 6.4761904762 |  | Current #2 motor | 2047 | 0.6444444444 | 400 | 0.2172 |  | L01Z400S05
 | PB0 | IN8 | 5 | 56 | 6.4761904762 |  | Speed control pot
 | PC1 | IN11 | 6 | 56 | 6.4761904762 |  | Control level (Hall sensor)
 | PC2 | IN12 | 7 | 56 | 6.4761904762 |  | +12 volt supply raw | 0 | 0.1525423729 | 19.0111111111
 | PC5 | IN15 | 8 | 56 | 6.4761904762 |  | +5 sensor supply voltage | 0 | 0.5465116279 | 5.3063829787
 |  | Temp | 9 | 480 | 46.8571428571 |  | Internal temperature sensor
 |  | Vref | 10 | 480 | 46.8571428571 |  | Internal voltage reference
 |  |  | DMA buffer | Num seq | 16
 |  |  |  | Total size | 320 |  |  | 10 | 10 | 0.5000 | 2.5000
 |  |  |  |  |  |  |  | 8.2 | 10 | 0.5495 | 2.7473
 |  |  |  | Time per seq | 145.5238095238 |  |  | 6.8 | 10 | 0.5952 | 2.9762
 |  |  | DMA buffer | Num seq | 16 | Per ½ dma
 |  |  |  | Per dma | 2328.380952381 | 1164.1904761905
 |  |  |  |  | 858.9659685864
 |  |  |  |  | DMA interrupt
 |  |  |  |  | Per sec | us per
 |  |  |  |  | 859 | 1164.1443538999

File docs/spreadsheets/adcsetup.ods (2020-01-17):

 | bpsensor |  | From datasheet formula
 | adc setup |  | Section | 5.3.21
 | 07/23/19 |  | 12-bit ADC | characteristics
 |  | Bus | 72
 |  | Divider | 6
 | K(sampling) | C(pf) | 12-bit ADC | 12bit | Rain |  | Sample tiime
 | 1.5 | 10 | 12 | 9.7040605278 | 1.29 |  | 0.1 |  |  | Divider |  |  |  |  |  |  |  |  |  | 14 | 14
 | 7.5 | 10 | 12 | 9.7040605278 | 6.40 |  | 0.6 |  | R1 (k) | R2 (k) | R|| (k) | Rseries(k) | Vdd (volts) | Ratio | Vin max | Vref | ADCvref | V1 | HV 100x | V1 | Vref scaled | ADCv1max
 | 13.5 | 10 | 12 | 9.7040605278 | 11.55 |  | 1.1 |  | 2200.00 | 18.70 | 18.54 | 2218.70 | 2.90 | 0.0084283589 | 344.1 | 1.200 | 27111.7 | 2.90 | 34407 | 47513 | 19660 | 65520 | 47511 | 0.7249603271
 | 28.5 | 10 | 12 | 9.7040605278 | 24.43 |  | 2.4 |  | 2200.00 | 18.00 | 17.85 | 2218.00 | 2.90 | 0.0081154193 | 357.3 | 1.200 | 27111.7 | 2.90 | 35734 | 47513 | 19660 | 65520 | 47511 | 0.7249603271
 | 41.5 | 10 | 12 | 9.7040605278 | 35.60 |  | 3.5 | ==> | 2200.00 | 15.00 | 14.90 | 2215.00 | 2.90 | 0.006772009 | 428.2 | 1.200 | 27111.7 | 2.90 | 42823 | 47513 | 19660 | 65520 | 47511 | 0.7249603271
 | 55.5 | 10 | 12 | 9.7040605278 | 47.62 |  | 4.6 |  | 2200.00 | 18.70 | 18.54 | 2218.70 | 3.30 | 0.0084283589 | 391.5 | 1.200 | 23825.5 | 3.30 | 39153 | 54067 | 19660 | 65520 | 54065 | 0.8249664307
 | 71.5 | 10 | 12 | 9.7040605278 | 61.36 |  | 6.0 |  | 2200.00 | 18.00 | 17.85 | 2218.00 | 3.30 | 0.0081154193 | 406.6 | 1.200 | 23825.5 | 3.30 | 40663 | 54067 | 19660 | 65520 | 54065 | 0.8249664307
dynamometer | 239.5 | 10 | 12 | 9.7040605278 | 205.63 |  | 20.0 | ==> | 2200.00 | 15.00 | 14.90 | 2215.00 | 3.30 | 0.006772009 | 487.3 | 1.200 | 23825.5 | 3.30 | 48730 | 54067 | 19660 | 65520 | 54065 | 0.8249664307
'MX
03/15/19 |  |  | ADC | Sample cycles | conv (us)
 | PA0 | IN0 | 1 | 41.0 | 4.4166666667 |  | Battery voltage
 | PA1 | IN1 | 1 | 41.0 | 4.4166666667 |  | DMOC+
 | PA2 | IN2 | 1 | 41.0 | 4.4166666667 |  | DMOC-
 | PA3 | IN3 | 1 | 41.0 | 4.4166666667 |  | spare
 | internal | IN17 | 1 | 252.0 | 22 |  | Internal temperature sensor
 | internal | IN18 | 1 | 252.0 | 22 |  | Internal voltage reference
 |  |  | DMA buffer | Num seq | 16
 |  |  |  | Total size ½ | 96
 |  |  |  | Time per seq | 61.6666666667
 |  |  | DMA buffer | Num seq PER ½ DMA | 16
 |  |  |  | Per dma | 986.6666666667
 |  |  |  |  | 1013.5135135135
 |  |  |  |  | DMA interrupt
 |  |  |  |  | Per sec | us per

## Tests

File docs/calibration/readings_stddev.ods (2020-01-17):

A | 64011.8 | 0.5 | 5.7 | 23974.7 | 26990.1 | 23854.4 | 1.4829618606 | 0.9440146568 | 9.6653361795 | 1.8218577889
A | 64008.7 | 0.5 | 5.6 | 23973.2 | 26987.1 | 23849.9 | 64010.4326039388 | 23973.6343544858 | 26969.1531728665 | 23852.5474835886
A | 64011.1 | 0.5 | 5.6 | 23974.1 | 26988.8 | 23853.5 | 0.0023167503 | 0.0039377203 | 0.035838486 | 0.0076380009
A | 64010.7 | 0.5 | 5.5 | 23974.1 | 26989.9 | 23852.2
A | 64012.1 | 0.5 | 5.5 | 23974 | 26989 | 23853.4
A | 64011.9 | 0.5 | 5.3 | 23973.6 | 26987.5 | 23852.9
A | 64010.7 | 0.5 | 5.5 | 23973.4 | 26987.8 | 23851.3
A | 64011.8 | 0.5 | 5.6 | 23974.4 | 26988.8 | 23854
A | 64012.5 | 0.5 | 5.7 | 23974.7 | 26989.5 | 23854.7
A | 64009.4 | 0.5 | 5.4 | 23973.7 | 26987.4 | 23849.7
A | 64012.2 | 0.5 | 5.4 | 23974.6 | 26990 | 23853.9
A | 64010.6 | 0.5 | 5.6 | 23974.3 | 26988.9 | 23851.4
A | 64013.1 | 0.6 | 5.9 | 23975.2 | 26988.8 | 23854.6
A | 64012.1 | 0.5 | 5.4 | 23974.4 | 26987.4 | 23853.1
A | 64011.3 | 0.5 | 5.5 | 23974.1 | 26987.3 | 23852.1
A | 64011.7 | 0.5 | 5.8 | 23974.4 | 26987.4 | 23853.4
A | 64010 | 0.5 | 5.6 | 23973.9 | 26985.8 | 23850.2
A | 64009.5 | 0.5 | 5.6 | 23974 | 26986.3 | 23849.5
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

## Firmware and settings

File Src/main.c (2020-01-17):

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

/* Includes ------------------------------------------------------------------*/
#include "main.h"
#include "cmsis_os.h"

/* USER CODE BEGIN Includes */

#include "stm32f1xx_hal.h"
#include <string.h>
#include "SerialTaskSend.h"
#include "SerialTaskReceive.h"
#include "CanTask.h"
#include "can_iface.h"
#include "canfilter_setup.h"
#include "getserialbuf.h"
#include "stackwatermark.h"
#include "yprintf.h"
#include "gateway_comm.h"
#include "gateway_CANtoPC.h"
#include "DTW_counter.h"
#include "yscanf.h"
#include "adctask.h"
#include "ADCTask.h"
#include "adcparams.h"
#include "adcparamsinit.h"
#include "gateway_PCtoCAN.h"
#include "morse.h"
#include "MailboxTask.h"
#include "GatewayTask.h"
#include "GenfieldTask.h"

/* USER CODE END Includes */

/* USER CODE BEGIN PTD */
struct CAN_CTLBLOCK* pctl0;	// Pointer to CAN1 control block

uint32_t debugTX1c;
uint32_t debugTX1c_prev;

uint32_t debug03;
uint32_t debug03_prev;

extern osThreadId SerialTaskHandle;
extern osThreadId SerialTaskReceiveHandle;
extern osThreadId CanTxTaskHandle;
extern osThreadId CanRxTaskHandle;
extern osThreadId GatewayTaskHandle;
extern osThreadId ADCTaskHandle;

uint8_t canflag;
uint8_t canflag1;

/* USER CODE END PTD */

ADC_HandleTypeDef hadc1;
DMA_HandleTypeDef hdma_adc1;

CAN_HandleTypeDef hcan;

TIM_HandleTypeDef htim1;
TIM_HandleTypeDef htim3;
TIM_HandleTypeDef htim4;

UART_HandleTypeDef huart1;
DMA_HandleTypeDef hdma_usart1_rx;
DMA_HandleTypeDef hdma_usart1_tx;

osThreadId defaultTaskHandle;
void SystemClock_Config(void);
static void MX_GPIO_Init(void);
static void MX_DMA_Init(void);
static void MX_CAN_Init(void);
static void MX_USART1_UART_Init(void);
static void MX_ADC1_Init(void);
static void MX_TIM4_Init(void);
static void MX_TIM1_Init(void);
static void MX_TIM3_Init(void);
void StartDefaultTask(void const * argument);

/**
  * @brief  The application entry point.
  * @retval int
  */
int main(void)
{
  /* USER CODE BEGIN 1 */
	BaseType_t ret;	   // Used for returns from function calls
	osMessageQId Qidret; // Function call return
	osThreadId Thrdret;
  /* USER CODE END 1 */
  

  /* MCU Configuration--------------------------------------------------------*/

  /* Reset of all peripherals, Initializes the Flash interface and the Systick. */
  HAL_Init();

  /* USER CODE BEGIN Init */
	DTW_counter_init();
  /* USER CODE END Init */

  /* Configure the system clock */
  SystemClock_Config();

  /* Initialize all configured peripherals */
  MX_GPIO_Init();
  MX_DMA_Init();
  MX_CAN_Init();
  MX_USART1_UART_Init();
  MX_ADC1_Init();
  MX_TIM4_Init();
  MX_TIM1_Init();
  MX_TIM3_Init();
  /* USER CODE BEGIN RTOS_MUTEX */
  /* add mutexes, ... */
  /* USER CODE END RTOS_MUTEX */

  /* USER CODE BEGIN RTOS_SEMAPHORES */
  /* add semaphores, ... */
  /* USER CODE END RTOS_SEMAPHORES */

  /* USER CODE BEGIN RTOS_TIMERS */
  /* start timers, add new ones, ... */
  /* USER CODE END RTOS_TIMERS */

  /* USER CODE BEGIN RTOS_QUEUES */
  /* add queues, ... */
  /* USER CODE END RTOS_QUEUES */

  /* Create the thread(s) */
  /* definition and creation of defaultTask */
  osThreadDef(defaultTask, StartDefaultTask, osPriorityIdle, 0, 304);
  defaultTaskHandle = osThreadCreate(osThread(defaultTask), NULL);

  /* USER CODE BEGIN RTOS_THREADS */
  /* add threads, ... */
/* =================================================== */

	/* Create serial task (priority) */
	// Task handle "osThreadId SerialTaskHandle" is global
	Thrdret = xSerialTaskSendCreate(0);	// Create task and set Task priority
	if (Thrdret == NULL) morse_trap(17);

	/* Add bcb circular buffer to SerialTaskSend for usart1 */
	#define NUMCIRBCB1  16 // Size of circular buffer of BCB for usart6
	ret = xSerialTaskSendAdd(&huart1, NUMCIRBCB1, 1); // dma
	if (ret < 0) morse_trap(1); // Panic LED flashing

	/* Add bcb circular buffer to SerialTaskSend for usart3 */
	#define NUMCIRBCB3  16 // Size of circular buffer of BCB for usart3
	ret = xSerialTaskSendAdd(&huart3, NUMCIRBCB3, 0); // char-by-char
	if (ret < 0) morse_trap(2); // Panic LED flashing

	/* Setup semaphore for yprint and sprintf et al. */
	yprintf_init();

	/* Create serial receiving task. */
	Thrdret = xSerialTaskReceiveCreate(1);
	if (Thrdret == NULL) morse_trap(21);

  /* definition and creation of CanTxTask - CAN driver TX interface. */
  Qidret = xCanTxTaskCreate(1, 32); // CanTask priority, Number of msgs in queue
	if (Qidret < 0) morse_trap(5); // Panic LED flashing

  /* definition and creation of CanRxTask - CAN driver RX interface. */
//  Qidret = xCanRxTaskCreate(1, 32); // CanTask priority, Number of msgs in extern osThreadId SerialTaskReceiveHandle;queue
//	if (Qidret < 0) morse_trap(6); // Panic LED flashing

	/* Setup TX linked list for CAN  */
   // CAN1 (CAN_HandleTypeDef *phcan, uint8_t canidx, uint16_t numtx, uint16_t numrx);
	pctl0 = can_iface_init(&hcan, 0, 32, 64);
	if (pctl0 == NULL) morse_trap(7); // Panic LED flashing
	if (pctl0->ret < 0) morse_trap(77);

	/* Setup CAN hardware filters to default to accept all ids. */
	HAL_StatusTypeDef Cret;
	Cret = canfilter_setup_first(1, &hcan, 15); // CAN1
	if (Cret == HAL_ERROR) morse_trap(9);

	/* Remove "accept all" CAN msgs and add specific id & mask, or id here. */
	// See canfilter_setup.h

	/* Genfield control. */
	Thrdret = xGenfieldTaskCreate(1);
	if (Thrdret == NULL) morse_trap(18);

	/* Create MailboxTask */
	Thrdret = xMailboxTaskCreate(3);
	if (Thrdret == NULL) morse_trap(19);

	/* Create Mailbox control block w 'take' pointer for each CAN module. */
	struct MAILBOXCANNUM* pmbxret;
	// (CAN1 control block pointer, size of circular buffer)
	pmbxret = MailboxTask_add_CANlist(pctl0, 16);
	if (pmbxret == NULL) morse_trap(16);

	/* Select interrupts for CAN1 */
	HAL_CAN_ActivateNotification(&hcan, \
		CAN_IT_TX_MAILBOX_EMPTY     |  \
		CAN_IT_RX_FIFO0_MSG_PENDING |  \
		CAN_IT_RX_FIFO1_MSG_PENDING    );

	/* Start CANs */
	HAL_CAN_Start(&hcan); // CAN1

	/* ADC summing, calibration, etc. */
	Thrdret = 	xADCTaskCreate(2);
	if (Thrdret == NULL) morse_trap(20);
	
/* =================================================== */

  /* USER CODE END RTOS_THREADS */

  /* Start scheduler */
  osKernelStart();
  
  /* We should never get here as control is now taken by the scheduler */

  /* Infinite loop */
  /* USER CODE BEGIN WHILE */
  while (1)
  {
    /* USER CODE END WHILE */

    /* USER CODE BEGIN 3 */
  }
  /* USER CODE END 3 */
}

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
/* USER CODE BEGIN Header_StartDefaultTask */
/**
  * @brief  Function implementing the defaultTask thread.
  * @param  argument: Not used 
  * @retval None
  */
/* USER CODE END Header_StartDefaultTask */
void StartDefaultTask(void const * argument)
{
  /* USER CODE BEGIN 5 */
	struct SERIALSENDTASKBCB* pbuf1 = getserialbuf(&huart1,96);
	if (pbuf1 == NULL) morse_trap(11);

	int ctr = 0; // Running count
	uint32_t heapsize;

// Copy of fast sum of ADC readings
int i;

// Number ADC readings per sec: 1153-1154.
extern uint32_t adcsumdb[6];// DMA sums
//extern uint32_t adcdbctr; // ADC DMA sum counter
double dt1;

extern struct GENFIELDFUNCTION genfieldfunction;
struct GENFIELDFUNCTION* pcf = &genfieldfunction;

osDelay(50); // Allow ADC task to get these initialized

// Temperature precomputed ratio check
if (pcf->padc->intern.dx25 < 0.1) morse_trap(48);

//double dxdvref = pcf->padc->intern.dvref * (1.0/4.3E-3);
if (pcf->padc->intern.dxdvref < 0.1) morse_trap(49);

// DTW time duration checks
extern uint32_t adcdbg2;

extern uint32_t dbgCE1;
uint32_t dbgCE1_prev = dbgCE1;

extern uint32_t dbgev04;


#define LOOPDELAY 1000
uint32_t tickct = xTaskGetTickCount();
int32_t loopdelay;

  /* Infinite loop */
  for(;;)
  {
//	tickct += LOOPDELAY;
//	loopdelay = (tickct - xTaskGetTickCount());
//	if (loopdelay < 1) morse_trap(333);
//   osDelay(loopdelay);
osDelay(1000);
//while( (dbggpsflag-dbggpsflag_prev) == 0);
//dbggpsflag_prev = dbggpsflag;

	HAL_GPIO_TogglePin(GPIOC,GPIO_PIN_13); // LED Green

#define SHOWSTACKWATERMARK
#ifdef SHOWSTACKWATERMARK
			// Following takes 1370791 sysclock ticks 19.0 ms (includes serial port wait)
			/* Display the amount of unused stack space for tasks. */
			yprintf(&pbuf1,"\n\n\r#%4i Unused Task stack space--", ctr++);
			stackwatermark_show(defaultTaskHandle,&pbuf1,"defaultTask---");
			stackwatermark_show(SerialTaskHandle ,&pbuf1,"SerialTaskSend");
			stackwatermark_show(CanTxTaskHandle  ,&pbuf1,"CanTxTask-----");
	//		stackwatermark_show(CanRxTaskHandle  ,&pbuf1,"CanRxTask-----");
			stackwatermark_show(MailboxTaskHandle,&pbuf1,"MailboxTask---");
			stackwatermark_show(ADCTaskHandle    ,&pbuf1,"ADCTask-------");
 		 stackwatermark_show(GenfieldTaskHandle,&pbuf1,"GenfieldTask-");
	stackwatermark_show(SerialTaskReceiveHandle,&pbuf1,"SerialReceiveTask");

			/* Heap usage (and test fp woking. */
  #define HEAPSIZELIST 
  #ifdef  HEAPSIZELIST
			heapsize = xPortGetFreeHeapSize();
			yprintf(&pbuf1,"\n\r#GetFreeHeapSize: total: %i free %i %3.1f%% used: %i\n\n\r",configTOTAL_HEAP_SIZE, heapsize,\
				100.0*(float)heapsize/configTOTAL_HEAP_SIZE,(configTOTAL_HEAP_SIZE-heapsize));
  #endif

#endif

#define SHOWSUMMEDADCCHANNELS
#ifdef  SHOWSUMMEDADCCHANNELS
		for (i = 0; i < 6; i++)
		{	
			yprintf(&pbuf1,"%7i ",adcsumdb[i]); // This is what routines work with
		}
		yprintf(&pbuf1, " :%7i %8.1f\n\r ", pcf->padc->intern.adcfiltemp, (double)(pcf->padc->intern.adcfilvref)/pcf->padc->intern.iiradcvref.pprm->scale);
#endif

#define SHOWEXTENDEDSUMMEDADCCHANNELS
#ifdef  SHOWEXTENDEDSUMMEDADCCHANNELS
		yprintf(&pbuf1, "\n\r     5v    cur1    cur2     12v    temp    vref\n\rA ");
		// Following loop takes about 450000 sysclock ticks 6.2 ms (includes waits for serial port)
		for (i = 0; i < 6; i++)
		{	
			yprintf(&pbuf1,"%8.1f",(double)(pcf->padc->chan[i].xsum[1])*(1.0/ADCEXTENDSUMCT));
		}
		yprintf(&pbuf1,"\n\r");
#endif

#define SHOWINTERNALTEMPERATURECALCULATIONS 
#ifdef SHOWINTERNALTEMPERATURECALCULATIONS
	/* Internal temperature computation check. */
	// The following takes 1418 sysclock ticks
	dt1 = (pcf->padc->intern.dx25 - (pcf->padc->intern.dxdvref * ((double)pcf->padc->intern.adcfiltemp / (double)pcf->padc->intern.adcfilvref )))  + pcf->padc->lc.calintern.drmtemp;

	yprintf(&pbuf1,"\n\rT degC: (doubles)%6.2f %6.2f (scaled int)%i\n\r", dt1,(double)pcf->padc->intern.itemp/(1<<ADCSCALEbits), adcdbg2,pcf->padc->intern.adccmpvref);
#endif

//      pcf->padc->chan[ADC1IDX_5VOLTSUPPLY].ival,  pcf->padc->v5.adcfil, 
//      pcf->padc->chan[ADC1IDX_12VRAWSUPPLY].ival, pcf->padc->v12.adcfil,
//#define SHOWADCDETAILS
#ifdef  SHOWADCDETAILS
	yprintf(&pbuf1,"\n\r%i %i %i %i %i %0.6f %0.4f : %0.4f\n\r",
      pcf->padc->v12.ival,
      pcf->padc->intern.adcfilvref,
      pcf->padc->intern.vref,
	   pcf->padc->v12.adcfil,
	   pcf->padc->lc.calintern.adcvdd,
      pcf->padc->v12.k,  
      (pcf->padc->v12.k * (double)pcf->padc->v12.ival * (1.0/(1<<ADCSCALEbits))), 
      pcf->padc->intern.dvref );

	yprintf(&pbuf1,"\n\rV v5: %0.3f  v12: %0.2f\n\r",
	  (pcf->padc->v5.k  * (double)pcf->padc->v5.ival  * (1.0/(1<<ADCSCALEbits))),
	  (pcf->padc->v12.k * (double)pcf->padc->v12.ival * (1.0/(1<<ADCSCALEbits))) );
#endif

#define SHOWHVUARTDATA
#ifdef  SHOWHVUARTDATA

yprintf(&pbuf1,"UART ctr: %i\n\ruart_hv%8i %9i %9i\n\r",dbgCE1-dbgCE1_prev,
  pcf->hv[0].hv,pcf->hv[1].hv,pcf->hv[2].hv);
dbgCE1_prev = dbgCE1;

/*
	double dscale;         // volts/tick
	double dhvc;           // HV calibrated
	uint32_t hvcal;        // Calibrated, scaled volts/adc tick
	uint32_t hvc;          // HV as scaled volts
	uint16_t hv;           // Raw ADC reading received from uart
*/
for (i = 0; i < 3; i++)
{
	pcf->hv[i].dhvc = (double)pcf->hv[i].dscale * (double)pcf->hv[i].hv;
}
yprintf(&pbuf1,"dscale%9.7f %9.7f %9.7f\n\r",pcf->hv[0].dscale,pcf->hv[1].dscale,pcf->hv[2].dscale);

yprintf(&pbuf1,"hvcal %9i %9i %9i\n\r",pcf->hv[0].hvcal,pcf->hv[1].hvcal,pcf->hv[2].hvcal);

yprintf(&pbuf1,"hvc   %9i %9i %9i\n\r",pcf->hv[0].hvc,pcf->hv[1].hvc,pcf->hv[2].hvc);

yprintf(&pbuf1,"hv    %9i %9i %9i\n\r",pcf->hv[0].hv,pcf->hv[1].hv,pcf->hv[2].hv);

yprintf(&pbuf1,"dhvc  %9.2f %9.2f %9.2f\n\r",pcf->hv[0].dhvc,pcf->hv[1].dhvc,pcf->hv[2].dhvc);

#endif

#define SHOWBATTERYLOWSTUFF
#ifdef  SHOWBATTERYLOWSTUFF

yprintf(&pbuf1,"ibattlow: %i  fbattlow: %0.2f  hv[0]: %i battnow: %0.2f\n\r",
   pcf->ibattlow, pcf->lc.fbattlow,
   pcf->hv[0].hv,
   (double)pcf->hv[0].dscale*(double)pcf->hv[0].hv);

yprintf(&pbuf1,"iprechgendv: %i hv[IDXHV3].hvc: %i\n\r",pcf->iprechgendv,pcf->hv[IDXHV3].hv);

#endif

#ifdef SHOWCANMSGCOUNTSATVARIOUSPOINTS
extern uint32_t dbgcantxctr;
extern uint32_t dbgcanrxctr;
uint32_t dbgcantxctr_prev = dbgcantxctr;
uint32_t dbgcanrxctr_prev = dbgcanrxctr;

extern uint32_t dbgmsg1ctr;
extern uint32_t dbgkactr;
uint32_t dbgmsg1ctr_prev = dbgmsg1ctr;
uint32_t dbgkactr_prev = dbgkactr;

extern uint32_t dbggpsflag;
uint32_t dbggpsflag_prev = dbggpsflag;;

uint32_t prev = 0;

extern uint32_t dbgmbxctr;
uint32_t dbgmbxctr_prev = dbgmbxctr;


yprintf(&pbuf1,"TIMER1 CT: %i rxct: %i txct: %i msg1ct: %i kact: %i diff: %i mbxctr: %i %i\n\r",dbgev04,dbgcanrxctr-dbgcanrxctr_prev, dbgcantxctr-dbgcantxctr_prev,
	dbgmsg1ctr-dbgmsg1ctr_prev,  dbgkactr-dbgkactr_prev,(int)(dbgcantxctr-dbgmsg1ctr),pcf->pmbx_cid_gps_sync->ctr-prev,dbgmbxctr-dbgmbxctr_prev);

dbgcanrxctr_prev = dbgcanrxctr;
dbgcantxctr_prev = dbgcantxctr;
dbgmsg1ctr_prev = dbgmsg1ctr;
dbgkactr_prev = dbgkactr;
prev = pcf->pmbx_cid_gps_sync->ctr;
dbgmbxctr_prev = dbgmbxctr;
#endif

//#define TESTHVBYPASSPIN
#ifdef  TESTHVBYPASSPIN
/* Should show '1' when jumper removed; '0' when present. */
int pin = 0;
if (HAL_GPIO_ReadPin(HVBYPASSPINPORT,  HVBYPASSPINPIN) == GPIO_PIN_SET) pin = 1;
yprintf(&pbuf1,"HV by-pass pin: %i\n\r",pin);
#endif

//#define TESTTHESHOLDPARAM
#ifdef  TESTTHESHOLDPARAM
int aa = (pcf->hv[IDXHV1].hvc - pcf->hv[IDXHV2].hvc);
if (aa < 0 ) aa = -aa;
int bb = pcf->iprechgendvb;
extern int dbgstmp;
yprintf (&pbuf1,"THRES: %7d %7d %7d %7d %7d\n\r",aa,bb,pcf->hv[IDXHV1].hvc,pcf->hv[IDXHV2].hvc,dbgstmp);
#endif

#define TESTRATIOMETRICCALIBRATION
#ifdef  TESTRATIOMETRICCALIBRATION
/*
struct ADCRATIOMETRIC
{
	struct IIRFILTERL iir;    // Intermediate filter params
	double drk5ke;    // Ratio k5/ke resistor dividers ratio (~1.0)
	double drko;      // Offset ratio: double (~0.5)
	double dscale;    // Scale factor
	uint32_t adcfil;  // Filtered ADC reading
	int32_t irk5ke;   // Ratio k5/ke ratio: scale int (~32768)
	int32_t irko;     // Offset ratio: scale int (~32768)
	int32_t iI;       // integer result w offset, not final scaling
}; */
yprintf(&pbuf1,"\n\rRATIOMETRIC: struct ADCRATIOMETRIC for cur1--\n\r");
yprintf(&pbuf1,"drko   %0.5f\n\rdscale %0.6f\n\r",
	pcf->padc->cur1.drko,    /* Offset ratio: double (~0.5)               */
	pcf->padc->cur1.dscale); /* Scale factor                              */
yprintf(&pbuf1,"adcfil %i\n\rirko   %i\n\riI     %i\n\r",
	pcf->padc->cur1.adcfil,  /* Filtered ADC reading                      */
	pcf->padc->cur1.irko,    /* Offset ratio: scale int (~32768)          */
	pcf->padc->cur1.iI );    /* integer result w offset, not final scaling*/

double dI = (pcf->padc->cur1.iI * pcf->padc->cur1.dscale) / (1<<ADCSCALEbits);
yprintf(&pbuf1,"calib %0.5f\n\r",dI);

// Debug
extern uint32_t dbgadcfil;
extern uint32_t dbgadcratio;
yprintf(&pbuf1,"dadcfil %i\n\rratio  %i\n\r",
dbgadcfil,
dbgadcratio);

yprintf(&pbuf1,"icurrentdisconnect %i iI %d\n\r",pcf->icurrentdisconnect,pcf->padc->cur1.iI);

#endif

#define TESTABSOLUTECALIBRATION
#ifdef  TESTABSOLUTECALIBRATION

double dt1 = ((double)pcf->padc->v5.ival * (1.0/(1<<ADCSCALEbits)) * pcf->padc->v5.dscale );
yprintf(&pbuf1,"v5--\n\radc v5  %i\n\rival    %i\n\rk       %8.6f\n\rdref   %9.6f\n\r",
pcf->padc->v5.adcfil,
pcf->padc->v5.ival,
pcf->padc->v5.k,
pcf->padc->intern.dvref);
yprintf(&pbuf1,"cmpvref %i\n\radcvref %i\n\rdscale  %8.6f\n\r5V %13.3f\n\r",
pcf->padc->intern.adccmpvref,
pcf->padc->intern.adcfilvref,
pcf->padc->v5.dscale,
dt1);

dt1 = ((double)pcf->padc->v12.ival * (1.0/(1<<ADCSCALEbits)) * pcf->padc->v12.dscale );
yprintf(&pbuf1,"v12--\n\radc v12 %i\n\rival    %i\n\rk       %8.6f\n\rdref   %9.6f\n\r",
pcf->padc->v12.adcfil,
pcf->padc->v12.ival,
pcf->padc->v12.k,
pcf->padc->intern.dvref);
yprintf(&pbuf1,"cmpvref %i\n\radcvref %i\n\rdscale  %8.6f\n\r12V %12.3f\n\r",
pcf->padc->intern.adccmpvref,
pcf->padc->intern.adcfilvref,
pcf->padc->v12.dscale,
dt1);

#endif

  } // END OF FOR LOOP

  /* USER CODE END 5 */ 
}

/**
  * @brief  Period elapsed callback in non blocking mode
  * @note   This function is called  when TIM2 interrupt took place, inside
  * HAL_TIM_IRQHandler(). It makes a direct call to HAL_IncTick() to increment
  * a global variable "uwTick" used as application time base.
  * @param  htim : TIM handle
  * @retval None
  */
void HAL_TIM_PeriodElapsedCallback(TIM_HandleTypeDef *htim)
{
  if (htim->Instance == TIM2) {
    HAL_IncTick();
  }
}

/**
  * @brief  This function is executed in case of error occurrence.
  * @retval None
  */
void Error_Handler(void)
{
  /* USER CODE BEGIN Error_Handler_Debug */
  /* User can add his own implementation to report the HAL error return state */

  /* USER CODE END Error_Handler_Debug */
}

#ifdef  USE_FULL_ASSERT
/**
  * @brief  Reports the name of the source file and the source line number
  *         where the assert_param error has occurred.
  * @param  file: pointer to the source file name
  * @param  line: assert_param error line source number
  * @retval None
  */
void assert_failed(uint8_t *file, uint32_t line)
{ 
  /* USER CODE BEGIN 6 */
  /* User can add his own implementation to report the file name and line number,
     tex: printf("Wrong parameters value: file %s on line %d\r\n", file, line) */
morse_trap(71);
  /* USER CODE END 6 */
}
#endif /* USE_FULL_ASSERT */

/************************ (C) COPYRIGHT STMicroelectronics *****END OF FILE****/

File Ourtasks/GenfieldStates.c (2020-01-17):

/******************************************************************************
* File Name          : GenfieldStates.c
* Date First Issued  : 01/06/2020
* Description        : States in Genfield function w STM32CubeMX w FreeRTOS
*******************************************************************************/

#include "FreeRTOS.h"
#include "task.h"
#include "cmsis_os.h"
#include "malloc.h"
#include "ADCTask.h"
#include "adctask.h"

#include "GenfieldStates.h"
#include "GenfieldTask.h"
#include "genfield_idx_v_struct.h"
#include "morse.h"
#include "adcparamsinit.h"

int dbgstmp;

void static transition_disconnected(struct GENFIELDFUNCTION* pcf);
static void transition_connecting(struct GENFIELDFUNCTION* pcf);
static void transition_disconnecting(struct GENFIELDFUNCTION* pcf);
static void new_state(struct GENFIELDFUNCTION* pcf, uint32_t newstate);
static void open_genfields(struct GENFIELDFUNCTION* pcf);

/* TIM4 CH3, CH4 drive Conatactor #1, #2 coils. */
extern TIM_HandleTypeDef htim4; // Needs this for autoreload period


/*
		case DISCONNECTED:
			GenfieldStates_disconnected(pcf);
			break;
		case CONNECTING:
			GenfieldStates_connecting(pcf);
			break;
		case CONNECTED:
			GenfieldStates_connected(pcf);
			break;
		case FAULTING:
			GenfieldStates_faulting(pcf);
			break;
		case FAULTED:
			GenfieldStates_faulted(pcf);
			break;
		case RESETTING:
			GenfieldStates_resetting(pcf);
			break;
		case DISCONNECTING:
			GenfieldStates_disconnecting(pcf);
			break;
*/
/* *************************************************************************
 * @brief	: 
 * *************************************************************************/

void GenfieldStates_otosettling_init(struct GENFIELDFUNCTION* pcf)
{
	/* Check if uart hv readings timer timed out. */
	if ((pcf->evstat & CNCTEVTIMER3) != 0)
	{ // Here, keep-alive uart rx timer timed out
		transition_faulting(pcf, NO_UART3_HV_READINGS);
		return;
	}

	/* Delay using data for a few cycles of readings. */
	if (pcf->hvuartctr < 50) return;

	transition_disconnecting(pcf);
	return;
}

/* ==== xDISCONNECTED ======================================= */
void static transition_disconnected(struct GENFIELDFUNCTION* pcf)
{ // Intialize disconnected state
	new_state(pcf,DISCONNECTED);
	return;
}
/* ==== DISCONNECTED ======================================== */
void GenfieldStates_disconnected(struct GENFIELDFUNCTION* pcf)
{
	uint32_t tmp;
	int16_t ret;

	if ((pcf->evstat & CNCTEVTIMER1) != 0)
	{ // Keep-alive timer timout
		transition_faulting(pcf,KEEP_ALIVE_TIMER_TIMEOUT);	
		return;	
	}

	/* Get rid of prior fault codes, mostly for display purposes. */
	pcf->faultcode = NOFAULT; // Reset code

	/* Update zero offset for Hall-effect current sensor. */
	if ((pcf->evstat & CNCTEVADC) != 0)
	{ // Here, new set of ADC readings
		ret = ratiometric_cal_zero_CURRENTTOTAL(pcf->padc);
		if (ret != 0)// morse_trap(55);
		{
			transition_faulting(pcf,HE_AUTO_ZERO_TOLERANCE_ERR);
		}
	}

	/* Install jumper to ignore HV readings. */
	// I/O pin shows '1' when jumper removed; '0' when present.
	if (HAL_GPIO_ReadPin(HVBYPASSPINPORT,  HVBYPASSPINPIN) != GPIO_PIN_SET)
	{ // Set configuration bit to skip HV reading logic
		pcf->lc.hwconfig |= PWMNOHVSENSOR;
	}
	else
	{
		pcf->lc.hwconfig &= ~PWMNOHVSENSOR;
	}

	/* Skip HV readings and battery string voltage check if no sensor. */
	if ((pcf->lc.hwconfig & PWMNOHVSENSOR) == 0)
	{ // Here, configuration: HV sensor is present

		if ((pcf->evstat & CNCTEVTIMER3) != 0)
		{ // Here: Not receiving readings from uart3 sensor
			transition_faulting(pcf,NO_UART3_HV_READINGS);
			return;
		}

		/* Check for battery string below threshold. */
		if (pcf->hv[IDXHV1].hv < pcf->ibattlow)
		{ // Here, battery voltage is too low (or readings missing!)
			transition_faulting(pcf,BATTERYLOW);
			return;
		}
	}

	/* Check if aux contacts match, if aux contacts present. */
	if ((pcf->lc.hwconfig & AUX1PRESENT) != 0)
	{ // Aux contacts are present
		tmp = HAL_GPIO_ReadPin(AUX1_GPIO_REG,AUX1_GPIO_IN);// read i/o pin
		if ((pcf->lc.hwconfig & AUX1SENSE) != 0)
		{ // Reverse sense of bit
			tmp ^= 0x1;
		}
		if (tmp != GPIO_PIN_RESET)
		{ // Transition to fault state; set fault code
			transition_faulting(pcf,GENFIELD1_OFF_AUX1_ON);
			return;			
		}
	}
	/* Check if aux contacts match, if aux contacts present. */
	if ((pcf->lc.hwconfig & AUX2PRESENT) != 0)
	{ // Aux contacts are present
		tmp = HAL_GPIO_ReadPin(AUX2_GPIO_REG,AUX2_GPIO_IN);// read i/o pin
		if ((pcf->lc.hwconfig & AUX2SENSE) != 0)
		{ // Reverse sense of bit
			tmp ^= 0x1;
		}
		if (tmp != GPIO_PIN_RESET)
		{ // Transition to fault state; set fault code
			transition_faulting(pcf,GENFIELD2_OFF_AUX2_ON); 
			return;			
		}
	}
	/* Keep-alive CAN msgs carry commands. */
	if ((pcf->evstat & CNCTEVCMDCN) != 0)
	{ // Here, ==> request to CONNECT <==
		transition_connecting(pcf);
		return;
	}
	/* JIC.  Be sure Updates have both coils de-energized. DMOC hw disabled */
	pcf->outstat &= ~(CNCTOUT00K1 | CNCTOUT01K2 | CNCTOUT06KAw | CNCTOUT07KAw |
        CNCTOUT04EN);
	pcf->outstat_prev |= (CNCTOUT00K1 | CNCTOUT01K2); // jic
	return;
}
/* *************************************************************************
 * void GenfieldStates_connecting(struct GENFIELDFUNCTION* pcf);
 * @brief	: CONNECTING state
 * *************************************************************************/
/* ===== xCONNECTING ==================================================== */
static void transition_connecting(struct GENFIELDFUNCTION* pcf)
{ // Intialize disconnected state

	/* Genfield configuration modes handled differently. */
	if ((pcf->lc.hwconfig & ONEGENFIELD) == 0)
	{ // Here, TWO GENFIELD mode

		/* Reset sub-states for connecting in this mode */
		pcf->substateC = CONNECT_C1;

		/* Set one-shot timer for genfield #1 closure delay */
		if (pcf->close1_k == 0) morse_trap(81);
		xTimerChangePeriod(pcf->swtimer2,pcf->close1_k, 2); 

		/* Energize coil #1: Battery_string-to-DMOC+ */
		pcf->outstat |= CNCTOUT00K1; // Energize coil during update section
		pcf->outstat &= ~CNCTOUT06KAw; // No pwm, JIC
	}
	else
	{ // Here, ONE GENFIELD W PRE-CHG RELAY mode

		/* Reset sub-states for connecting in this mode */
		pcf->substateC = CONNECT_C1B;

		/* Set one-shot timer for pre-chg relay (#2) closure delay */
		if (pcf->close2_k == 0) morse_trap(81);
		xTimerChangePeriod(pcf->swtimer2,pcf->close2_k, 2); 

		/* Energize coil #2: (Pre-charge relay) */
		pcf->outstat |= CNCTOUT01K2; // Energize coil during update section
		pcf->outstat &= ~CNCTOUT07KAw; // No pwm, JIC
	}
	pcf->evstat &= ~CNCTEVTIMER2; // Reset sw2 timer timeout bit

	/* Update main state */
	new_state(pcf,CONNECTING);
	return;
}
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

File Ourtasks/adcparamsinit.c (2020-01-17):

/******************************************************************************
* File Name          : adcparamsinit.c
* Date First Issued  : 03/09/2019
* Board              : DiscoveryF4
* Description        : Initialization of parameters for ADC app configuration
*******************************************************************************/
/* 
This is where hard-coded parameters for the ADC are entered.

Later, this may be replaced with a "copy" of the flat file in high flash, generated
by the java program from the sql database.
*/
#include "adcparamsinit.h"
#include "adcparams.h"
#include "ADCTask.h"
#include "morse.h"

static void ratiometric_cal(struct ADCRATIOMETRIC* p, struct ADCCALHE* plc);

/*                        Min  Typ  Max 
Internal reference F103: 1.16 1.20 1.26 V 
Internal reference F407: 1.18 1.20 1.24 V 
*/
// Define limits for initialization check
#define VREFMIN (1.15)
#define VREFMAX (1.27)

/* *************************************************************************
void adcparamsinit_init(struct ADCFUNCTION* p);
 *	@brief	: Load structs for compensation, calibration and filtering all ADC channels
 * @param	: p = Pointer to struct "everything" for this ADC module
 * *************************************************************************/

/* Reproduced for convenience

#define ADC1IDX_5VOLTSUPPLY   0   // PA0 IN0  - 5V sensor supply
#define ADC1IDX_CURRENTTOTAL  1   // PA5 IN5  - Current sensor: total battery current
#define ADC1IDX_CURRENTMOTOR1 2   // PA6 IN6  - Current sensor: motor #1
#define ADC1IDX_12VRAWSUPPLY  3   // PA7 IN7  - +12 Raw power to board
#define ADC1IDX_INTERNALTEMP  4   // IN17     - Internal temperature sensor
#define ADC1IDX_INTERNALVREF  5   // IN18     - Internal voltage reference

#define ADC1PARAM_COMPTYPE_NONE      0     // No supply or temp compensation applied
#define ADC1PARAM_COMPTYPE_RATIOVDD  1     // Vdd (3.3v nominal) ratiometric
#define ADC1PARAM_COMPTYPE_RATIO5V   2     // 5v ratiometric with 5->Vdd measurement
#define ADC1PARAM_COMPTYPE_RATIO5VNO 3     // 5v ratiometric without 5->Vdd measurement
#define ADC1PARAM_COMPTYPE_VOLTVDD   4     // Vdd (absolute), Vref compensation applied
#define ADC1PARAM_COMPTYPE_VOLTVDDNO 5     // Vdd (absolute), no Vref compensation applied
#define ADC1PARAM_COMPTYPE_VOLTV5    6     // 5v (absolute), with 5->Vdd measurement applied
#define ADC1PARAM_COMPTYPE_VOLTV5NO  7     // 5v (absolute), without 5->Vdd measurement applied

#define ADC1PARAM_CALIBTYPE_RAW_F  0    // No calibration applied: FLOAT
#define ADC1PARAM_CALIBTYPE_OFSC   1    // Offset & scale (poly ord 0 & 1): FLOAT
#define ADC1PARAM_CALIBTYPE_POLY2  2    // Polynomial 2nd ord: FLOAT
#define ADC1PARAM_CALIBTYPE_POLY3  3    // Polynomial 3nd ord: FLOAT
#define ADC1PARAM_CALIBTYPE_RAW_UI 4    // No calibration applied: UNSIGNED INT
*/
double adcdtmp;

void adcparamsinit_init(struct ADCFUNCTION* p)
{
/* Reproduced for convenience 
struct ADCFUNCTION
{
	struct ADCGENFIELDLC lc;    // Local Copy of parameters
	struct ADCINTERNAL    intern;// Vref & temperature
	struct ADCABSOLUTE    v12;   // Supply: raw 12v
	struct ADCABSOLUTE    v5;    // Supply: regulated 5v
	struct ADCRATIOMETRIC cur1;  // Current sensor #1
   struct ADCRATIOMETRIC cur2;  // Current sensor #2
	struct ADCCHANNEL	 chan[ADC1IDX_ADCSCANSIZE]; // ADC sums, calibrated endpt
	uint32_t ctr; // Running count of updates.
};
struct ADCINTERNAL
{
	struct IIRFILTERL iiradcvref; // Intermediate filter params: vref 
	struct IIRFILTERL iiradctemp; // Intermediate filter params: temperature sensor

	uint32_t adcfilvref;  // Filtered ADC[Vref]
	uint32_t adcfiltemp;  // Filtered ADC[temperature]

	uint32_t adcvref;    // Do I need this?
	uint32_t adccmpvref; // scaled vref compensated for temperature

	double dvref;        // (double) vref computed from calibration params
	uint32_t vref;       // (scaled) vref computed from calibration params

	uint32_t iRslope;    // (scaled) Reciprocal of temperature sensor slope
	uint32_t iv25s;      // (scaled) (V25 * iRslope)
	double   V25;        // (double) Computed V25 (no)
	uint32_t vrefRs;     // (scaled) Vref / slope
	uint32_t irmtemp;    // (scaled) calibration temperature
	uint32_t itemp;      // (scaled) temperature (degC)
};
*/
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

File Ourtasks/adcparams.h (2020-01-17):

/******************************************************************************
* File Name          : adcparams.h
* Date First Issued  : 06/15/2019
* Board              : DiscoveryF4
* Description        : Parameters for ADC app configuration
*******************************************************************************/
/* CALIBRATION NOTES:

5 volt supply calibration:
[Do this first: This calibration is applied to all 5v sensors]
- Measure 5v supply
- Measure Vdd
- Display ADCsum[5v supply]
Compute--
Ratio 'sensor5vcal' = (Vdd/V5volt) * (ADCsum[5v supply]/(4095*numdmaseq)
 where numdmaseq = number of ADC scans per 1/2 dma (i.e. number readings in sum)

Ratiometric 5v sensor calibration:
- With 5v supply calibration compiled-in:
- Measure Sensor voltage: Vx
- Display:
  . ADCsum[sensor]
  . Va = (V5 * ratio)/ADCsum[5v]
Compute
  Calibration ratio = ADCsum[sensor]/Va

                    Min  Typ  Max 
Internal reference: 1.16 1.20 1.24 V

Temperature sensor specs
                 Min  Typ  Max
Average slope    4.0  4.3  4.6 mV/°C
Voltage at 25 °C 1.34 1.43 1.52 V

NOTE: 5v supply w LM2596 dc-dc switcher
60 mv peak=peak triangle wave w two 100u caps
20 mv peak-peal by adding 1000u cap

*/

#ifndef __ADCPARAMS
#define __ADCPARAMS

#include "iir_filter_lx.h"
#include "adc_idx_v_struct.h"
#include "cic_filter_l_N2_M3.h"

#define ADC1DMANUMSEQ        16 // Number of DMA scan sequences in 1/2 DMA buffer
#define ADC1IDX_ADCSCANSIZE   6 // Number ADC channels read
#define ADCSCALEbits         15 // 2^x scale large
#define ADCSCALEbitsy         7 // 2^x scale small
#define ADCSCALEbitsitmp      3 // 2^x scale just enough
#define ADCEXTENDSUMCT     1024 // Sum of 1/2 DMA sums for addition averaging
#define ZTOLERANCE         0.05 // +/- tolerance for re-adjustment of Hall_effect sensor zero


/* ADC reading sequence/array indices                         */
/* These indices -=>MUST<= match the hardware ADC scan sequence    */
#define ADC1IDX_5VOLTSUPPLY   0   // PA0 IN0  - 5V sensor supply
#define ADC1IDX_CURRENTTOTAL  1   // PA2 IN2  - Current sensor: total battery current
#define ADC1IDX_CURRENTMOTOR  2   // PA4 IN4  - Current sensor: motor
#define ADC1IDX_12VRAWSUPPLY  3   // PA7 IN7  - +12 Raw power to board
#define ADC1IDX_INTERNALTEMP  4   // IN17     - Internal temperature sensor
#define ADC1IDX_INTERNALVREF  5   // IN18     - Internal voltage reference

/* Calibration option.                                    */
/* Calibration is applied after compensation adjustments. */
#define ADC1PARAM_CALIBTYPE_RAW_F  0    // No calibration applied: FLOAT
#define ADC1PARAM_CALIBTYPE_OFSC   1    // Offset & scale (poly ord 0 & 1): FLOAT
#define ADC1PARAM_CALIBTYPE_POLY2  2    // Polynomial 2nd ord: FLOAT
#define ADC1PARAM_CALIBTYPE_POLY3  3    // Polynomial 3nd ord: FLOAT
#define ADC1PARAM_CALIBTYPE_RAW_UI 4    // No calibration applied: UNSIGNED INT
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

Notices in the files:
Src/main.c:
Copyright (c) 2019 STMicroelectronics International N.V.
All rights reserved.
